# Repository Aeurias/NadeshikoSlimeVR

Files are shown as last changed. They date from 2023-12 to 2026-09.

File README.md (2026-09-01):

<h1 align="center">
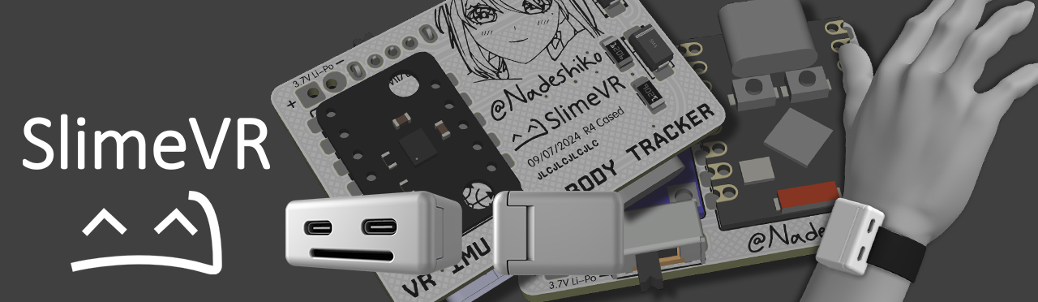
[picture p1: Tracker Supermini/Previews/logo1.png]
@Nadeshiko's Mini SlimeVR

@Nadeshiko's Supermini SlimeVR

</h1>

> [!IMPORTANT]
> For the old WEMOS D1 Mini variant please view the [D1 branch here](https://github.com/Aeurias/NadeshikoSlimeVR/tree/WEMOS-D1-Mini)

These are some of the smallest WiFi module based SlimeVR trackers possible, similar to [Gorbit99's Tiny Slime](https://github.com/gorbit99/tiny-slime), as small as extension trackers! The idea was for these to be a replacement for wired extension trackers, whose cables can get in the way and are prone to damage, and be a more useable and comfortable size for tracking locations such as shoulders, lower arms, neck, or head.

Due to how small these are, there is no option to connect an extension tracker, as that will only increase the overall size and cost of a whole tracker set.

@Nadeshiko's Supermini SlimeVRs run on a [ESP32-C3 Supermini](https://www.aliexpress.com/item/1005005877531694.html) with an IMU IC of your choice that has the same module profile as widely used SlimeVR IMU-module format like the [Mumo ICM-45686](https://shop.slimevr.dev/products/slimevr-mumo-breakout-module-v1-icm-45686-qmc6309)'s. They use the [TP4056 Unprotected lithium charger](https://www.aliexpress.com/item/1005005468881238.html) module for 3.7V LiPo batteries.

- 2.6cm x 3.8cm PCB design.
- Easy and very cheap to build.
- No wires needed to be soldered.
- Lightweight and smooth, clean case looks.
- 25mm strap width is supported.

## Index

- [PCB](#pcb)
- [Case](#cases)
- [Components](#components)
- [Basic Assembly Guide](#assembly)
- [Resources](#resources)
- [Detailed Assembly Guide](#detailed-assembly)
- [C3 WiFi Antennas](#esp32-c3-supermini-wifi-antennas)
- [Flashing Firmware](#flashing)
- [How to order PCB/3DPrints](#ordering)
- [Support](#support)

## PCB

The PCB lets every component be soldered on without any wire connections between the modules. This includes the diodes and resistors for battery sense and charge protection. The ESP32-C3 Supermini is on the back side to save on size and cost; a JST 2mm 2-pin connector can be added to make battery connections easier; an SK12D07VG 3-pin switch will be used to turn the tracker on or off.

PCBs can be ordered from [JLCPCB](https://cart.jlcpcb.com/quote/), [Elecrow](https://www.elecrow.com/pcb-manufacturing.html), [PCBGOGO](https://www.pcbgogo.com/pcb-fabrication-quote.html), [NextPCB](https://www.nextpcb.com/pcb-quote#/pcb-quote) or your preferred low cost PCB manufacturer.

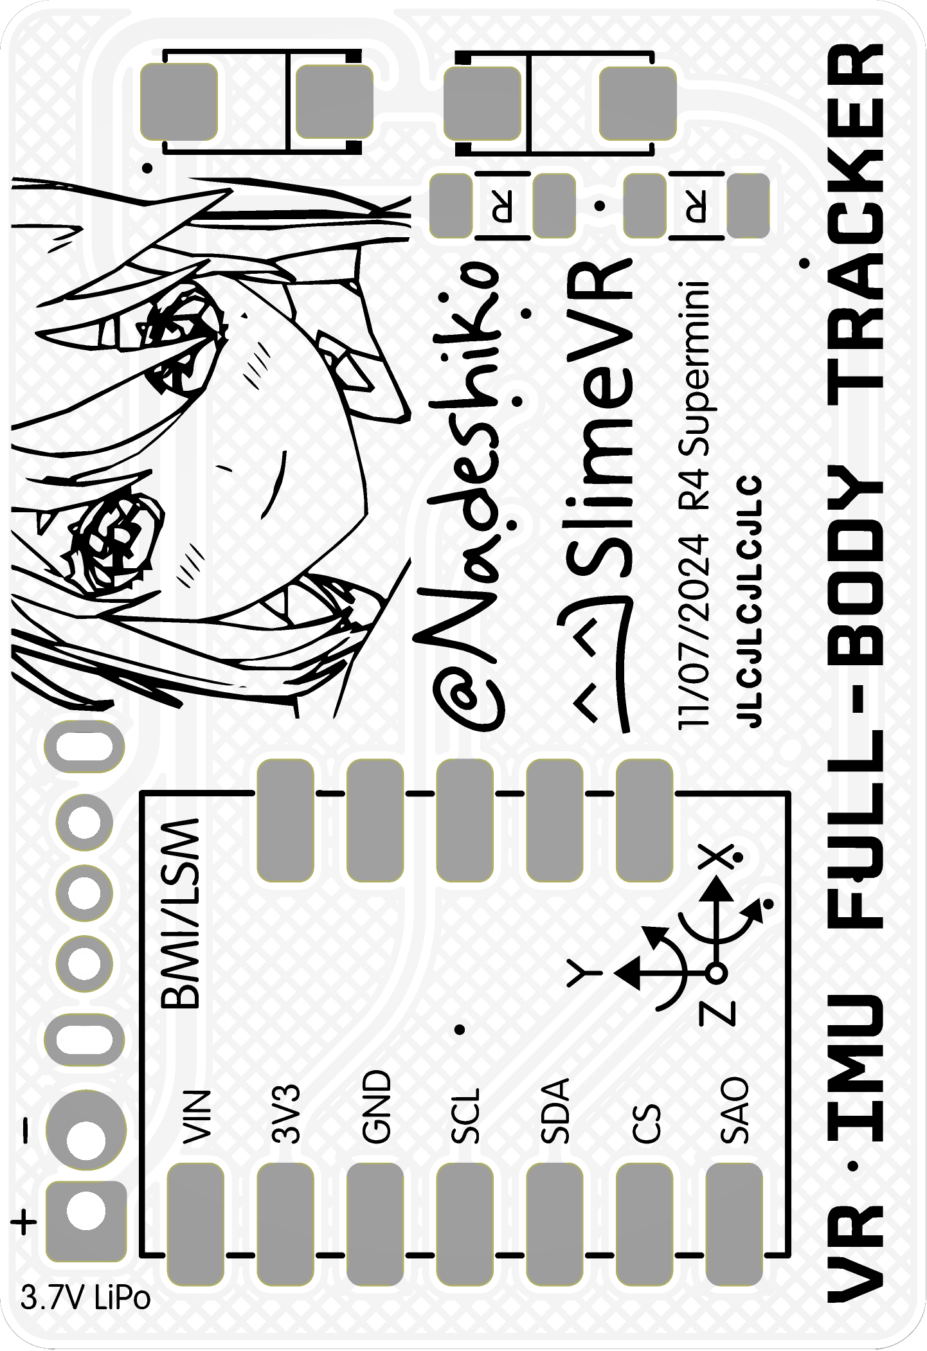
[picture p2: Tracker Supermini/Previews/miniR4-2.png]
Supermini Front
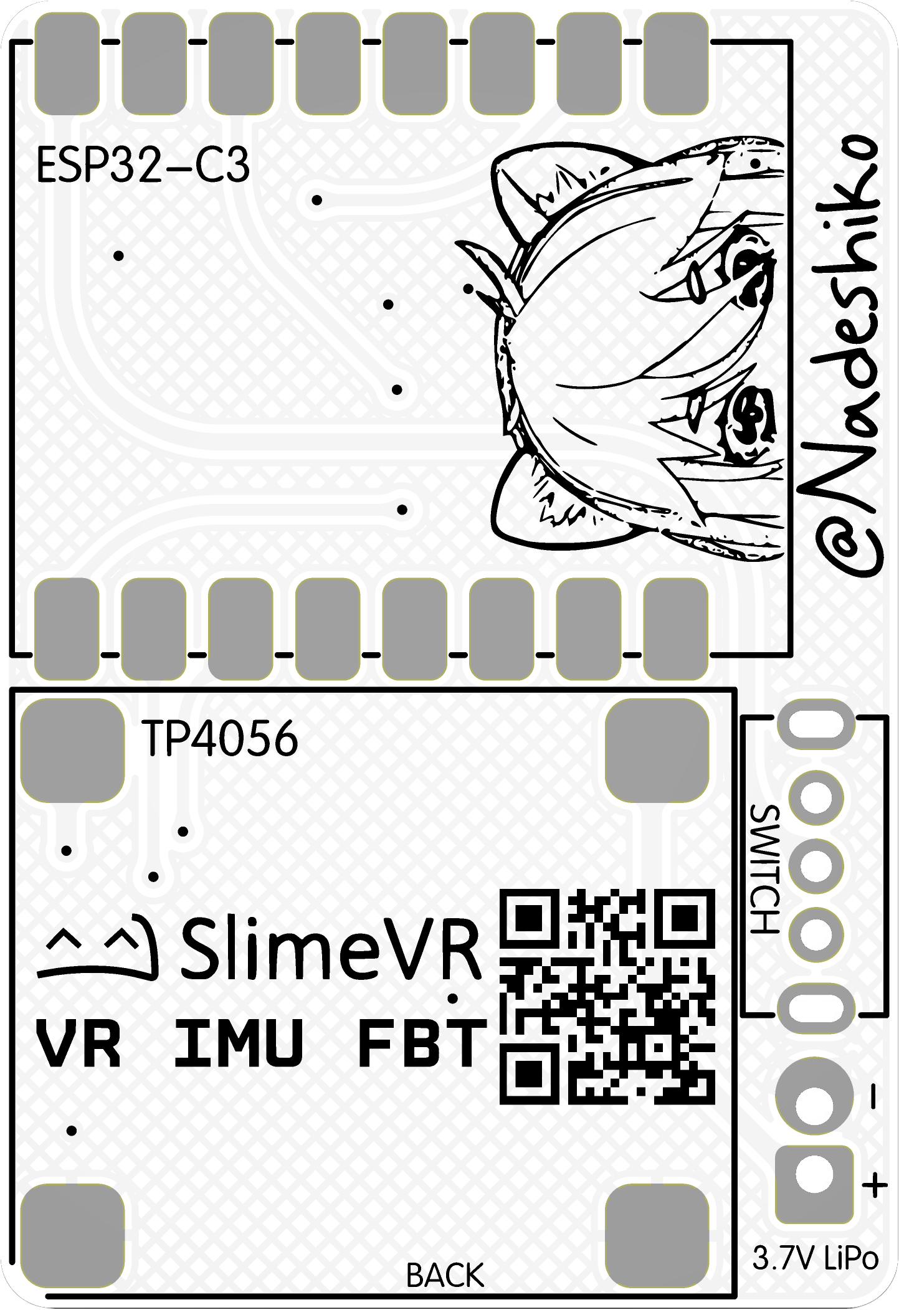
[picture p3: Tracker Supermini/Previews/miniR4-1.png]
Supermini Back
<div align="center">&nbsp;&nbsp;&nbsp;&nbsp;</div>

<p align="center">PCB Front/Back - 26mm x 38mm</p>

## Cases

The standard tracker case can house a 3.7V LiPo with Max LiPo cell dimensions 6x25x40mm, a 602535 or similar LiPo is recommended. There is also a double/taller battery variant of the case which allows stacking two batteries in parallel or a thick LiPo for longer runtime, this case is 5.6mm taller allowing LiPo cells to be 12mm tall.

The cases has been designed according to [JLCPCB/JLC3DP resin 3D printing guidelines](https://jlc3dp.com/help/article/212-3D-Printing-Design-Guideline). The case can be ordered from [JLC3DP](https://jlc3dp.com/3d-printing-quote) or [Elecrow](https://www.elecrow.com/3d-printing-service.html), and the resin to select on your order is up to you. I prefer the [**9000R**](https://jlc3dp.com/help/article/195-9000R---Photosensitive-Resin), [**CBY**](https://jlc3dp.com/help/article/437-CBY-Photosensitive-Resin), [**Black Resin**](https://jlc3dp.com/help/article/198-Black-Resin--Photosensitive-Resin), or equivalent low cost options..

It prints as two parts: a snap-fit closure with holes for strap, the TP4056 charger and ESP32-C3 USB ports, and the power switch.

25mm strap can be fitted to the cases; the best one to use is the non-slip elastic kind with plastic buckles and tri-buckles in the same size to make it easier to remove, more comfortable and adjustable. Hook and Loop style of strap can also be used.

The files for the standard case are:

- [NadeshikoSupermini-TOP.stl](Tracker%20Supermini/3D%20Print%20STL/NadeshikoSupermini-TOP.stl)

- [NadeshikoSupermini-BASE.stl](Tracker%20Supermini/3D%20Print%20STL/NadeshikoSupermini-BASE.stl)

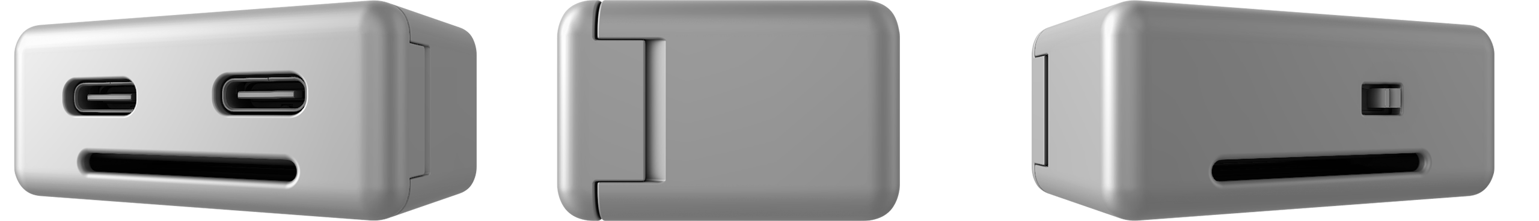
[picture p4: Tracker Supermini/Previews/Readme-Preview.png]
MiniPreview


<div align="center">30.2mm x 46.0mm × 19.52mm - 8.67cm³</div>

The files for the double stack battery case are:

- [NadeshikoSupermini-Double-Battery-TOP.stl](Tracker%20Supermini/3D%20Print%20STL/NadeshikoSupermini-Double-Battery-TOP.stl)

- [NadeshikoSupermini-Double-Battery-BASE.stl](Tracker%20Supermini/3D%20Print%20STL/NadeshikoSupermini-Double-Battery-BASE.stl)

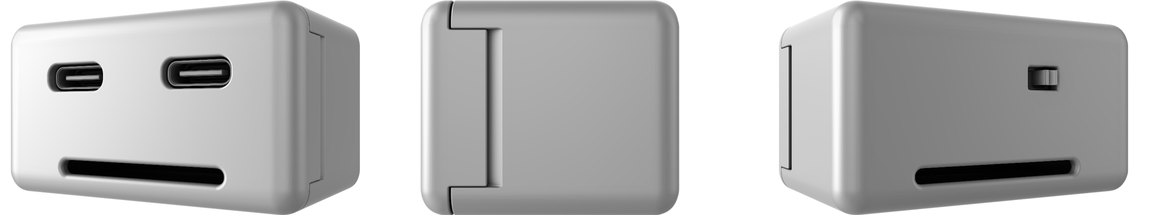
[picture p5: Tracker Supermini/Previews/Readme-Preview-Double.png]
MiniPlusPreview


<div align="center">30.2mm x 46mm × 25.12mm - 10.13cm³</div>

## Components

The component cost should come out to around £8/€9/$11 per tracker with the recommended ICM-45686 IMUs.
Quantity and prices listed below are per tracker expense and quantity used of each component.
Some of the smaller items are sold in pack sizes of 10/50/100 etc. which can build multiple trackers with.
Prices here are listed without any shipping costs, or pack sizes, or taxes, and may not be latest.

| Components per SlimeVR Tracker |  QTY  | £ | Link |
| --- | ----: | ----: | --- |
| @Nadeshiko Mini PCB | 1 |  0.39 | [JLCPCB](https://jlcpcb.com/) |
| @Nadeshiko Mini Case | 1 |  0.55 | [JLC3DP](https://jlc3dp.com/) |
| ESP32-C3 SuperMini V1/V2 | 1 |  1.59 | [AliExpress](https://www.aliexpress.com/item/1005006391993583.html) |
| SlimeVR Mumo ICM-45686 IMU Module | 1 |  5.00 | [SlimeVR](https://shop.slimevr.dev/products/slimevr-mumo-breakout-module-v1-icm-45686-qmc6309) |
| TP4056 Unprotected Charger Type-C | 1 |  0.11 | [AliExpress](https://www.aliexpress.com/item/32646649119.html) |
| SK12D07VG Slide Switch in 3/4/5mm | 1 |  0.04 | [AliExpress](https://www.aliexpress.com/item/1005005786809487.html) |
| 1206/3216 Resistors in 100K Ohm | 2 |  0.01 | [AliExpress](https://www.aliexpress.com/item/32982307507.html) |
| SS34 DO214AC Diodes | 2 |  0.01 | [AliExpress](https://www.aliexpress.com/item/1005005707508759.html) |
| LiPo Battery 6x25x40mm or smaller | 1 |  0.72 | [EHAO](https://www.aliexpress.com/w/wholesale-EHAO.html) or [XINJ](https://www.aliexpress.com/store/4885018/pages/all-items.html) or [ROGRAPO](https://www.aliexpress.com/store/910326412/pages/all-items.html) @AliExpress |

| Mounting Straps for Trackers | Link |
| --- | --- |
| 25mm Hook & Loop | [AliExpress](https://www.aliexpress.com/item/1005006326126306.html) |
| 25mm Elastic Strap & Buckles | [AliExpress](https://www.aliexpress.com/item/1005006096453678.html) |
| 25mm Tri Glide Adjustable Buckles | [AliExpress](https://www.aliexpress.com/item/1005006144047161.html) |
| 25mm Release Buckles | [AliExpress](https://www.aliexpress.com/item/1005006082194146.html) |

## Assembly

Using a solder helping hand will make putting everything on the PCB much easier! While soldering, keep your solder iron's tip tinned with solder when not in use to protect from oxidation. Use plenty of flux for surface mounts. Clean the PCBs from excess flux after soldering and testing, you can use PCB cleaner, isopropyl alcohol, acetone or nail varnish remover.

The basic steps of assembly for the main trackers are:

- [ ] 2x 1206 100K resistor and 2x SS34 diodes soldered in the correct orientation on the PCB.
- [ ] Solder an unprotected TP4056 charger flush to the PCB.
- [ ] Solder on a SK12D07VG slide switch.
- [ ] Solder the IMU module to the PCB.
- [ ] Solder the ESP32-C3 Supermini module flush to the PCB.
- [ ] Solder on the LiPo battery with the power switch in the OFF position in correct polarity.

Flashing:

- [ ] Power switch still in the OFF position; Flash firmware using the SlimeVR server or VSCode.
- [ ] When flashing, you want to choose `BOARD_LOLIN_C3_MINI` as the board.
- [ ] In Advanced options, change SDA Pin to `"6"`, SCL Pin to `"7"`, INT Pin to`"5"` and LED Pin to `"8"`.
- [ ] In Battery Sense section, select `BAT_EXTERNAL`, Shield Resistance to `0`, Battery Shield R1 & R2 to `100` kOhm, Battery Sense Pin to `1`.
- [ ] OPTIONAL: Use polyimide tape or equivalent on sharp corners and the LiPo battery to protect it from puncture.
- [ ] OPTIONAL: Remove the C3 chip antenna and add 29 to 31mm tinned wire for better WiFi signal (20-30dB better signal strength).

> [!TIP]
> When soldering make sure to use correct iron temperatures, a high quality flux cored solder wire and liquid flux in syringe. A multimeter will come extremely handy to test each component and solder joints. Check some guides on YouTube first if you've never soldered before!

## Detailed-Assembly

#### Step 1 - Resistors and Diodes

The diodes have an orientation marked by lines, which will match the line on the PCB diode footprint.
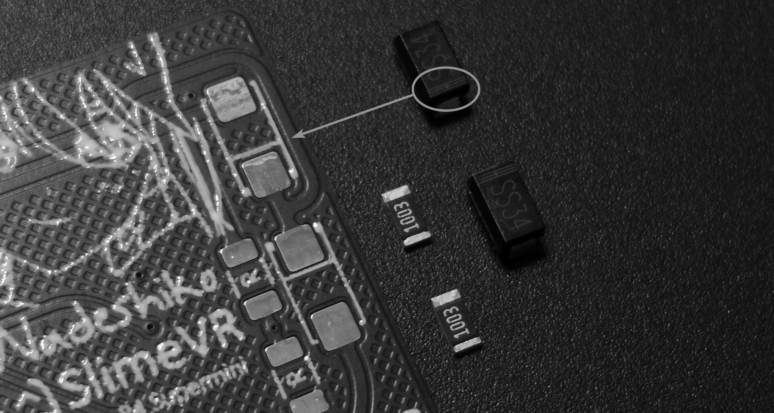
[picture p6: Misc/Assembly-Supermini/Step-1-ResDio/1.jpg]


Solder on the 100K resistors first, any orientation. Flux to make them easier to solder as it helps hold them and easier to clean later.
Add a smidge of solder on one of each of the diodes pads, so it can be the first pad to solder the diodes down to.
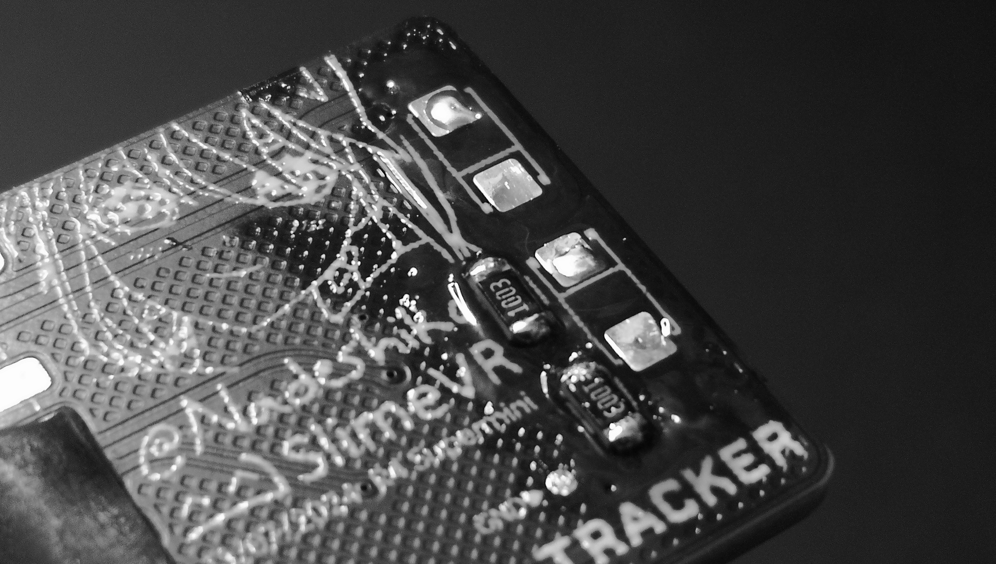
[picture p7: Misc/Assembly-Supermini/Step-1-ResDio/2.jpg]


Should look like this, with the diodes lines facing each other:
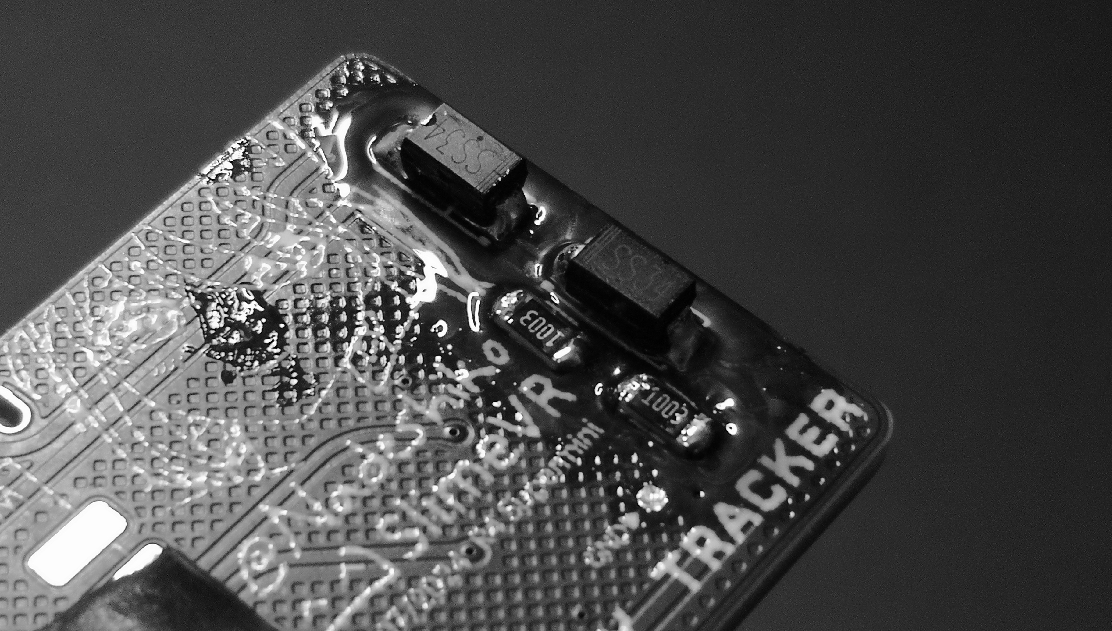
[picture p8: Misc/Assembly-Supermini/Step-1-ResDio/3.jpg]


#### Step 2 -  IMU Module

I'm using the Mumo ICM45686 IMU module here from the SlimeVR store, clamp it down on the backside of the PCB where you did the resistor/diodes with your solder helper clamps. I've added tiny bit of flux on the pads before doing this too:
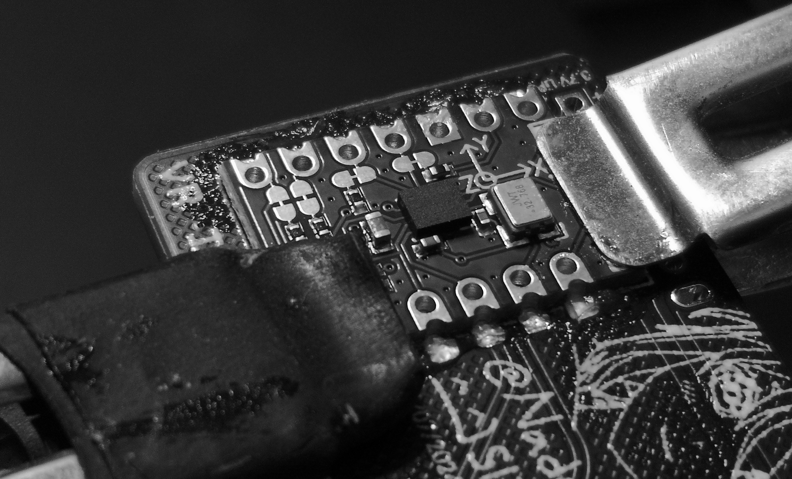
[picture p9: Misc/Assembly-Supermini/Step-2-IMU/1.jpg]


Solder the edge castellated holes of the IMU. If your module of choice does not have those and has drill holes, just use a bit more flux and do the holes instead.
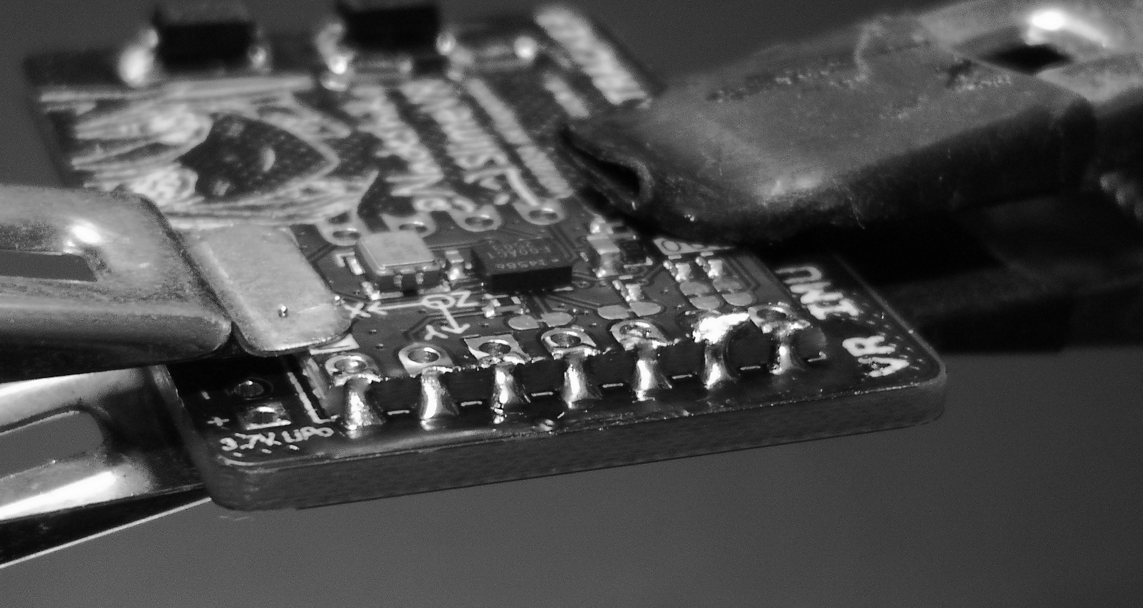
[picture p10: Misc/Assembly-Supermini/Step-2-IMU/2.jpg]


Do both left and right side, and double check visually to make sure there aren't any missed.
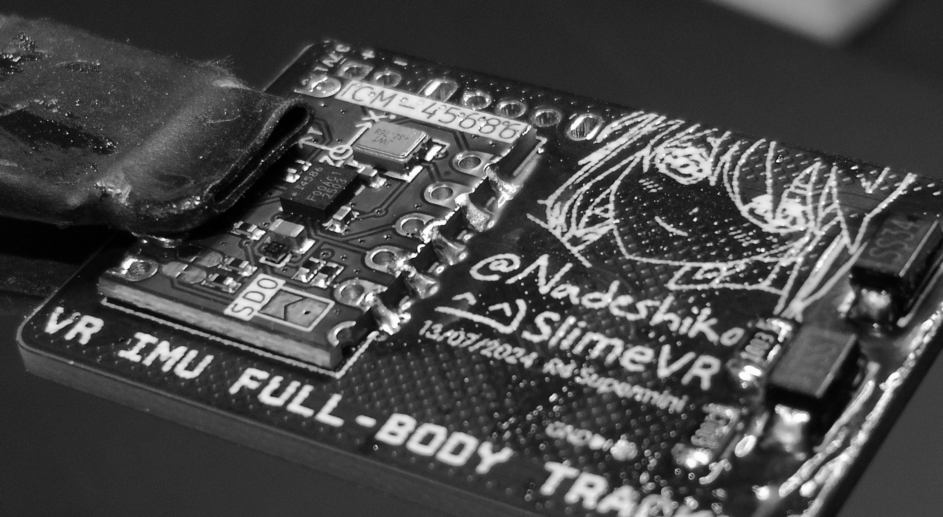
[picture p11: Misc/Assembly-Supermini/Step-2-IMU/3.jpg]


#### Step 3 -  Power Switch

The switch goes on the other side like shown in the image. It has its footprint there.
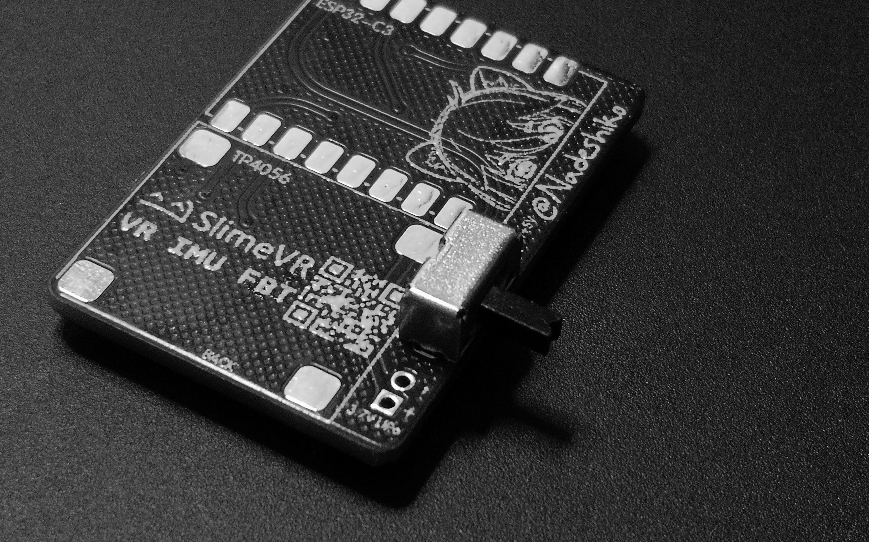
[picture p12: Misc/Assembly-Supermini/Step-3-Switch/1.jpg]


Clamp it flat to the PCB, but still have access to at least one of the legs on the backside of the PCB to solder initially.
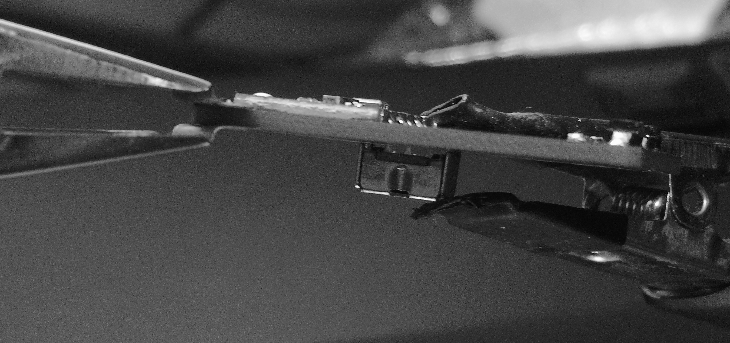
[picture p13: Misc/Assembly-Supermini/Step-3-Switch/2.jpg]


Flux those legs/pins and solder.
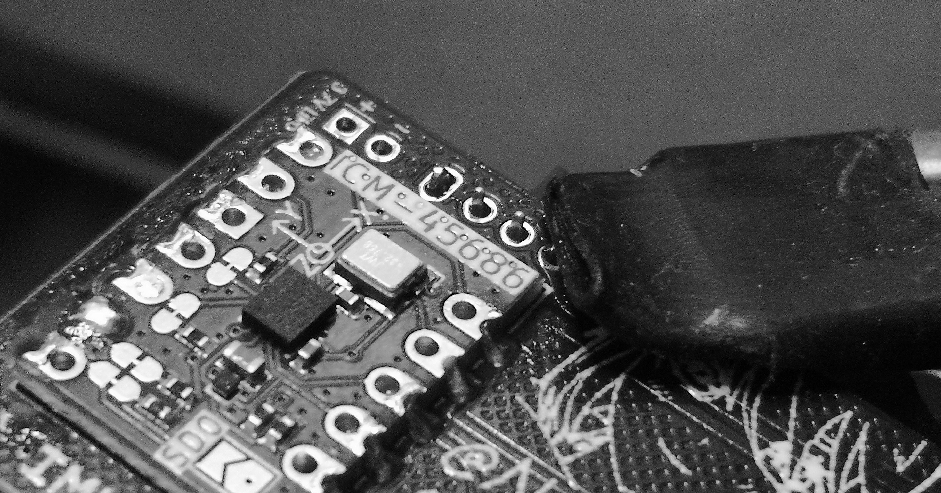
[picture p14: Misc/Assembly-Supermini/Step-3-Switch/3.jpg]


Flux will help pull solder through to the other side, which will make the switch very sturdy:
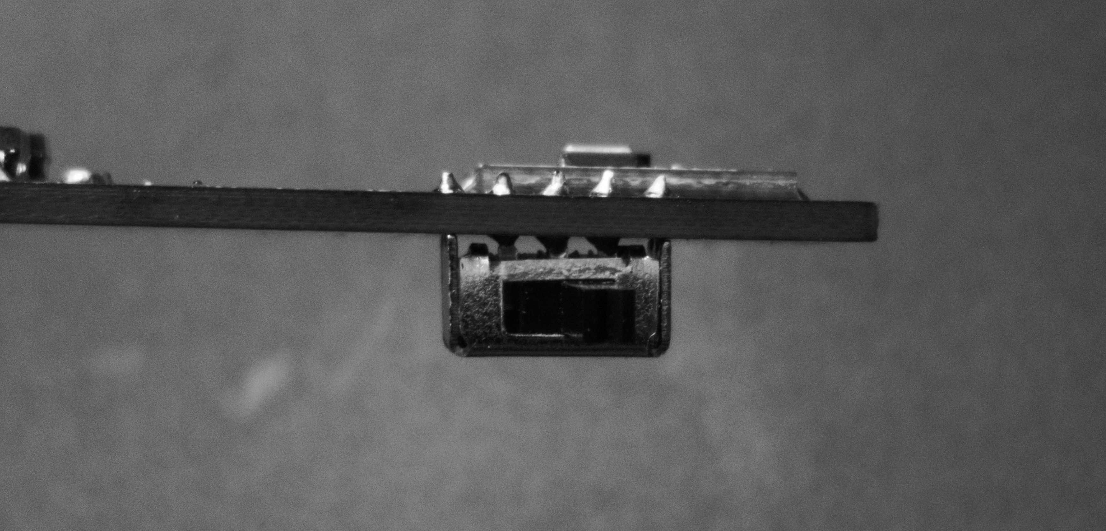
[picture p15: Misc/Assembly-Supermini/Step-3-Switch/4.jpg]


That does the backside of the PCB, you can clean the excess flux so its not sticky n ewwee for the rest of steps.
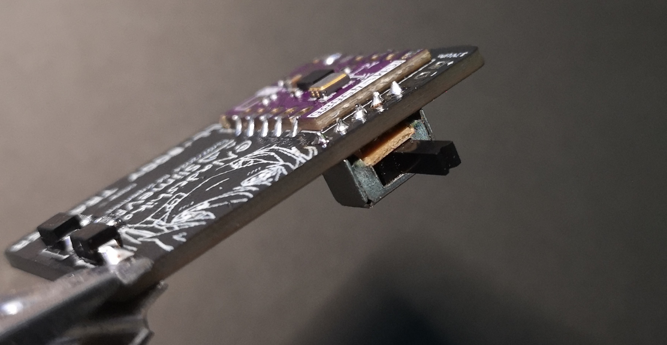
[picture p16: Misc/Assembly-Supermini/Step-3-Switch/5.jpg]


#### Step 4 - ESP32-C3 Supermini Module

There are few a Supermini C3 variants out there. The most common of these is the one on the right with the C3 antenna only which works perfectly for these slimes. For this guide, I'm using an C3 Supermini Plus which has the same footprint profile as the normal C3 Supermini, but has an flexible IPEX antenna included with it for improved range. I will also explain later on how to use the IPEX antenna properly on the Plus as it requires a small modification for it to work, or how to modify the non IPEX ones for better signal strength.


Soldering the C3 is same as the IMU earlier. Just slightly larger and few more pads. Start with fluxing the pads slightly.
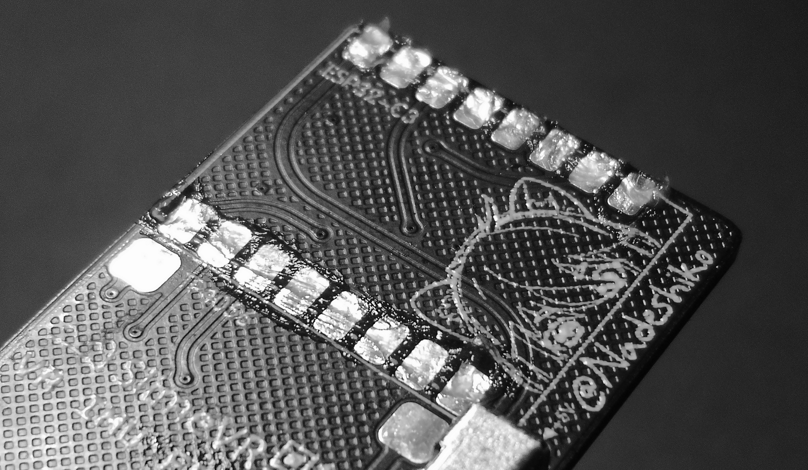
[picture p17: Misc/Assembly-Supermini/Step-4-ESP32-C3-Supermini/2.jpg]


Clamp down the C3 with your solder helping hands in the correct position, lined up with the footprint on the PCB.
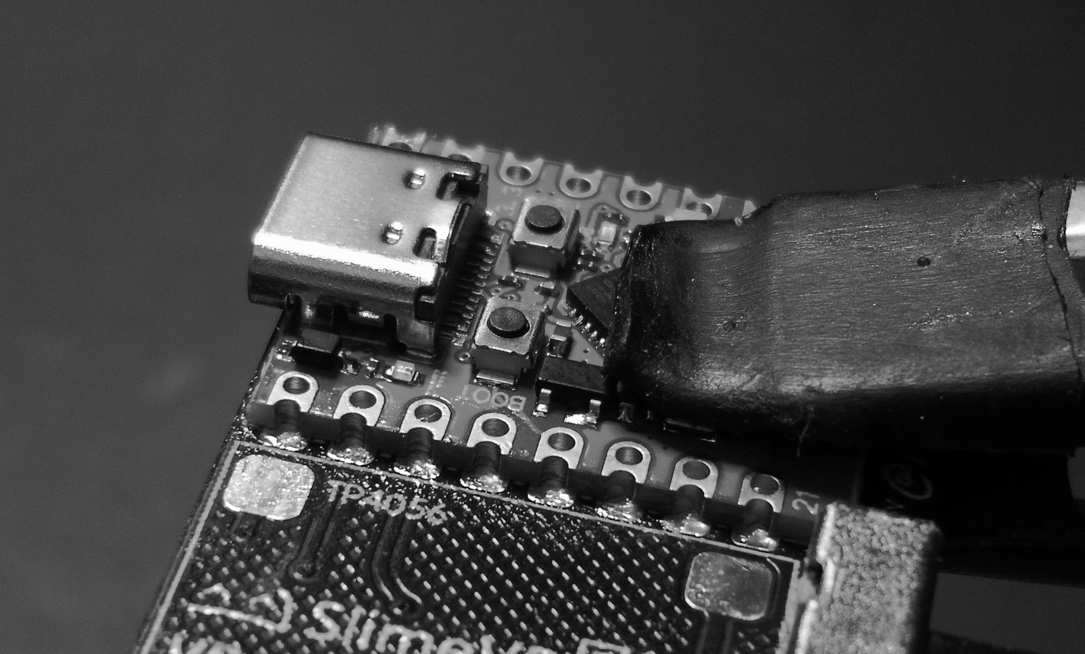
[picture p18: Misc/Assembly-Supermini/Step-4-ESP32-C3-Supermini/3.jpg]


Solder the edge castellated holes of the C3, both left and right side, and double check visually to make sure there aren't any missed pads.
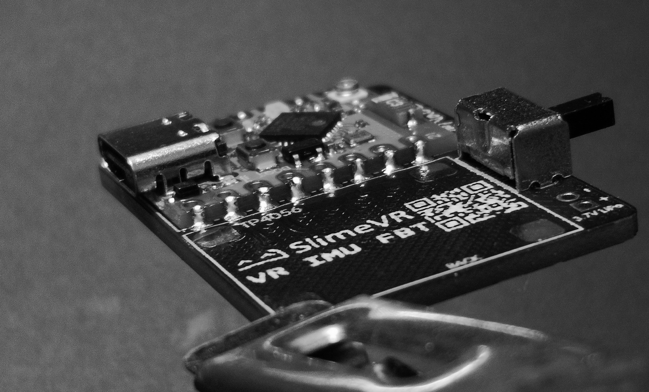
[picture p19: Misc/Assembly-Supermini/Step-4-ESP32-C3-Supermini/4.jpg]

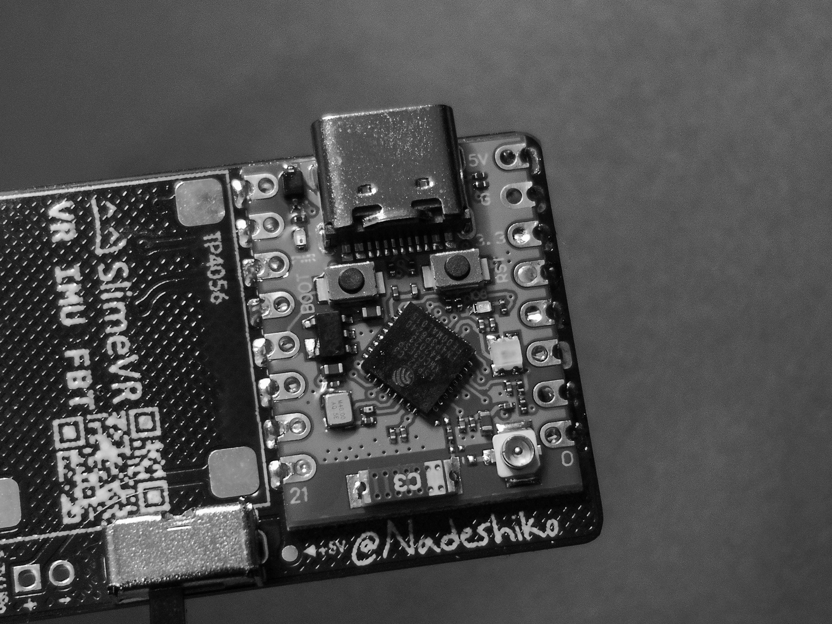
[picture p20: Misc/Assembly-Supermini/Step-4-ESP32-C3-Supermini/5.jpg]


#### Step 5 - TP4056 Unprotected Charger Module

The TP4056 3.7v Lithium battery charging module comes in many sizes and USB styles. You want the unprotected variant with 4 holes:
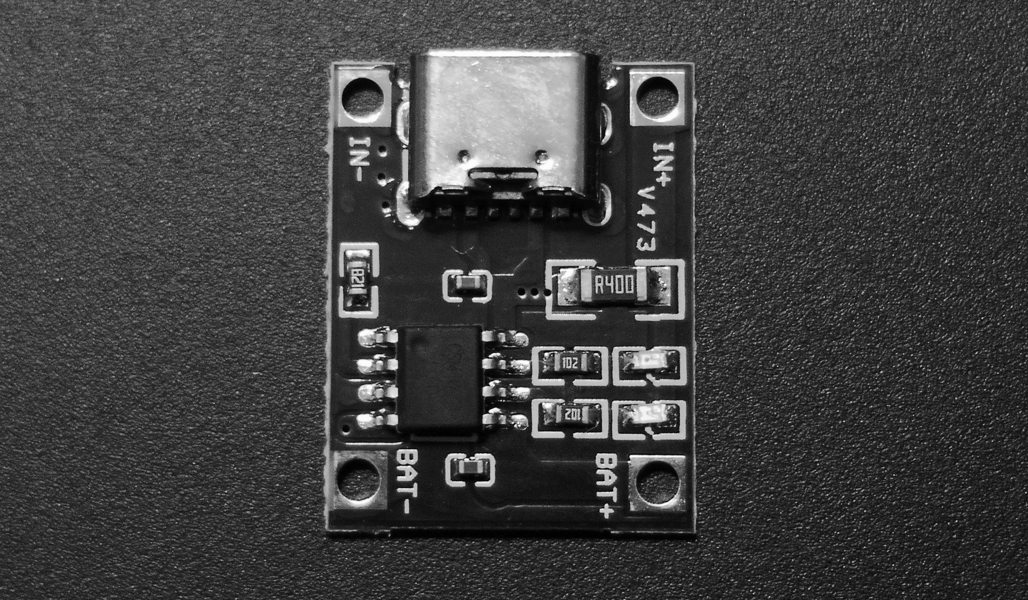
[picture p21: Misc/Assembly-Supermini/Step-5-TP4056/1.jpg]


Flux the PCB pads and even some of the holes on the TP4056 just to make it easier to solder and then clamp it down.
It may not align with the footprint perfectly like mine, as these come with small variance in dimension between vendors.
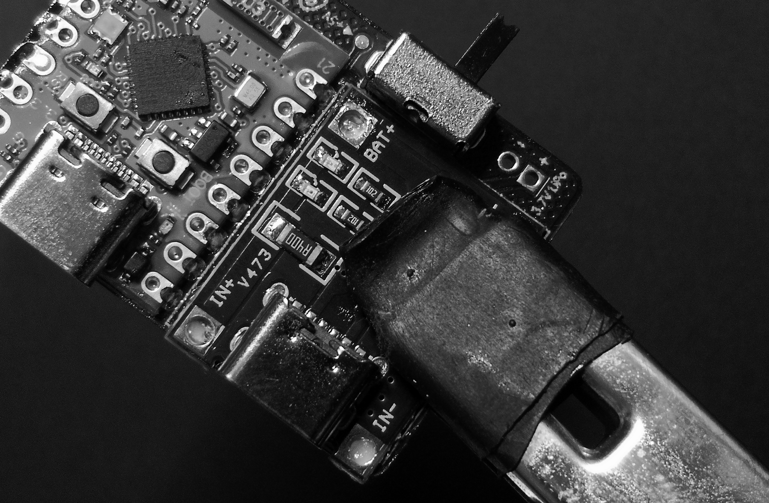
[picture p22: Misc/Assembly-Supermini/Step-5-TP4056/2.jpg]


There may be a small overhang on the TP4056, mostly okay, but this can be filed/sanded down if it causes issues with fitment into the case.
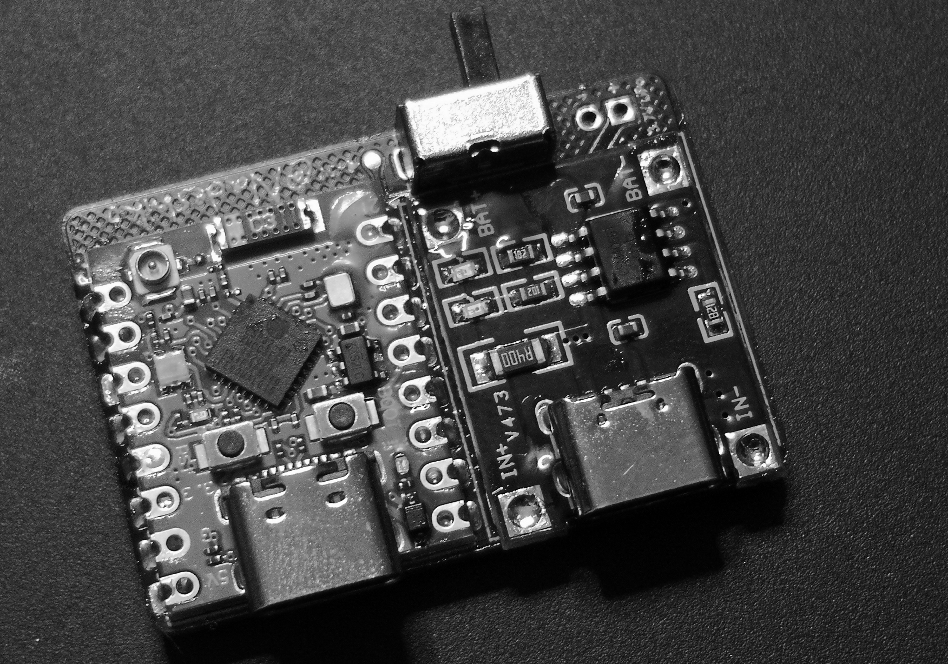
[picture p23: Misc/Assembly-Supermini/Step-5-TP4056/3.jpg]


#### Step 6 -  3.7v LiPo Battery

The tracker is basically complete and useable, and can be flashed right away. But we'll continue this guide with the battery. I am using a 602030 battery here that I was able to find super cheap on AliExpress, which is 6mm x 20mm x 30mm as the name states. This Supermini PCB/Case SlimeVR can house up to a 6x25x40mm battery. Thicker batteries like 7mm could fit, but we need a gap between the battery and the inside wall of the case for the strap to pass through.

We need to cut the wire down as it's arrives bit too long. Cut them short around where the arrow is indicated. For smaller batteries you might need a bit more wire, and less for larger batteries, so its fits in the case easier.
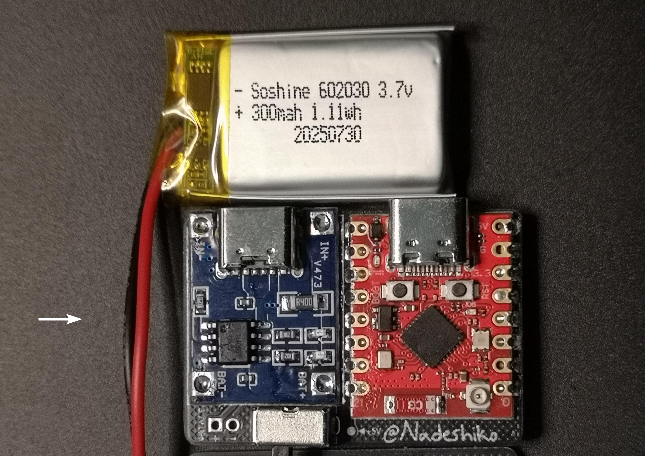
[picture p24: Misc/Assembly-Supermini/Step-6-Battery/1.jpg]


Strip the ends of the cable so we can solder it on the PCB.
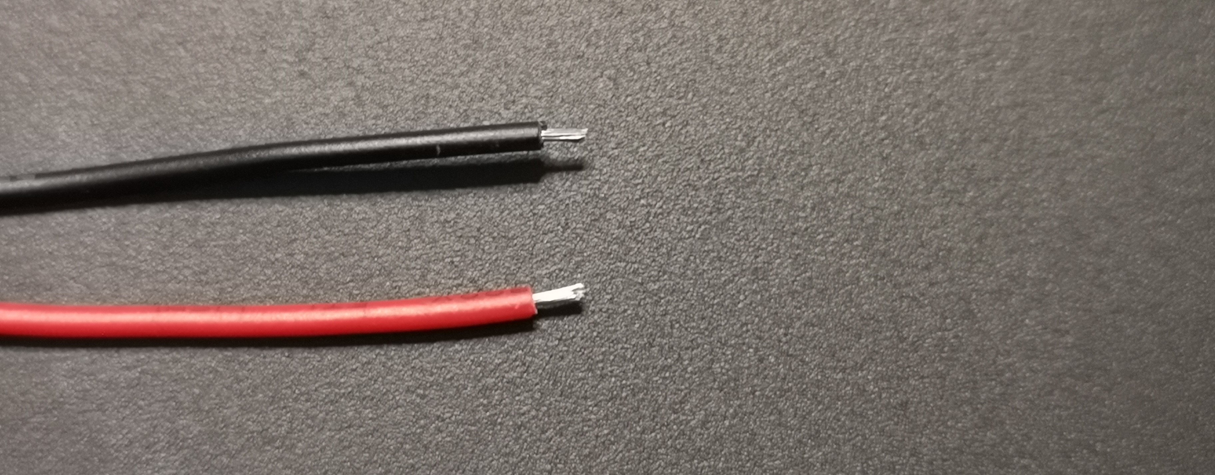
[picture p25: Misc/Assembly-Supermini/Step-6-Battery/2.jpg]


Flux the cable ends and the +/- holes on the PCB and solder it up. Making sure it's correct polarity.
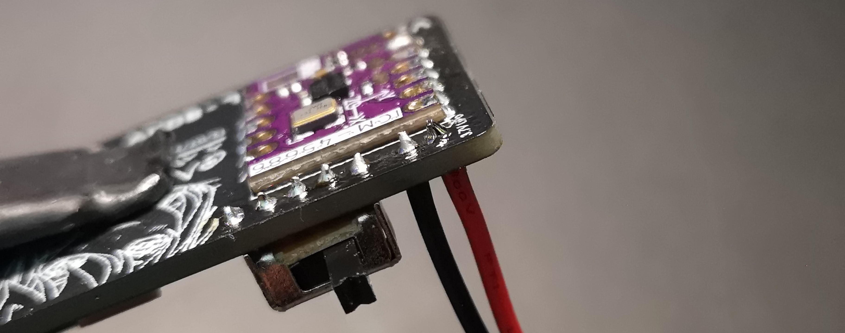
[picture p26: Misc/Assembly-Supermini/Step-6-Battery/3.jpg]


The wires can be shaped/bent around, so the battery sits nicely on top of the modules/USB's.
If wires too long you can redo it and cut it shorter. If too short, you can undo the yellow polyimide tape on the battery and redo the wires on it.
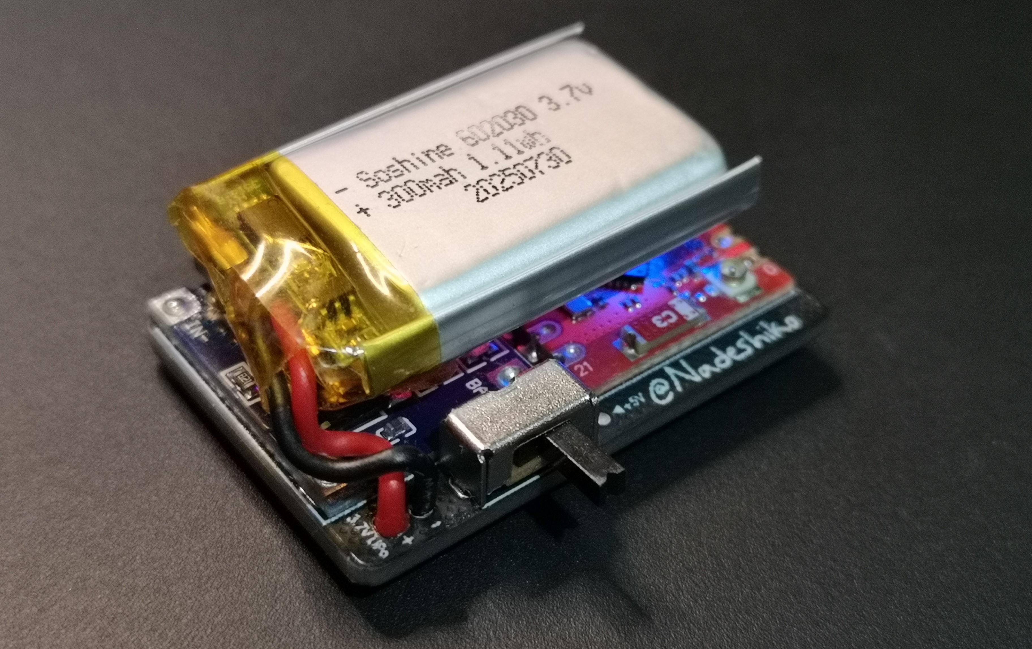
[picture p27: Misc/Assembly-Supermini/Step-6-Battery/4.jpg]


## ESP32-C3 Supermini WiFi Antennas

There are two antenna modifications you can do to improve WiFi range and signal reliability on the ESP32-C3 Supermini V1 & V2. Both involve removing the stock C3 chip antenna.

### Option A - IPEX Antenna (Plus/V2 variant only)

For the Plus/V2 variant C3 Supermini, you must solder a bridge between the two points marked with the green arrow to use the IPEX antenna.
This alone is enough to get the antenna to work, however the C3 chip antenna must be removed as it causes imperfect impedance matching and signal loss.
As some power leaks into the unused antenna, this reduces the efficiency and dB of the external antenna. For that, simply de-solder the red arrow marked C3 chip antenna, and then bridge green point with solder or a 0 Ohm resistor, and attach the IPEX antenna.
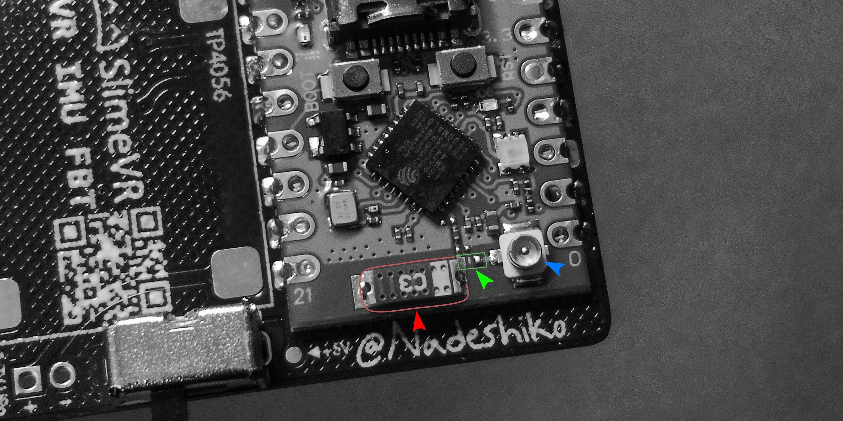
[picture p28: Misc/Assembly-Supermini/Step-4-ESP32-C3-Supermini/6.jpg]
IPEX


### Option B - Quarter-Wave Wire Antenna (any C3 Supermini variant) - Recommended

Instead of using an IPEX antenna, you can solder a simple wire directly onto the C3 chip antenna's main solder pad to create a Quarter-Wave ($\lambda/4$) antenna. This works on any C3 Supermini variant and gives around 25 to 30 dBm signal strength gain over the stock chip antenna.

**Why a wire antenna?** The stock chip antenna on the C3 is compact but weak. A quarter-wave wire antenna is tuned to 2.4 GHz WiFi and naturally approaches the 50-ohm impedance the ESP32-C3's radio is designed for, meaning more power goes into the air and less is reflected back into the ESP32 chip.

**Wire length:** Cut a piece of solid core wire to **31mm**. This length comes from the quarter-wave formula adjusted for the velocity factor of copper wire:

$$L = \frac{c}{f \times 4} \times K \approx 30.6 \text{ mm} \times 0.96 \approx 29.5 \text{ mm}$$

Where *c* is the speed of light (~300,000 km/s), *f* is 2.45 GHz (center of the band), and *K* is the velocity factor (~0.96 for copper wire).

> [!TIP]
> The extra ~1.5mm accounts for the solder joint which doesn't radiate efficiently, the C-shape bending which creates stray capacitance that makes the antenna electrically shorter than its physical length, and the fact that WiFi spans 2.412 to 2.484 GHz so the true ideal length varies by channel. Starting slightly long and trimming is standard practice in RF, since you can always cut shorter but can't add length back.

**Steps:**

1. De-solder and remove the C3 chip antenna from the board.
2. Cut a piece of wire to 31mm. Tin the wire with solder if it's stranded so its one solid conductor.
3. Solder the wire onto the chip antenna's main solder pad.
4. Bend the wire into a **C shape** so it loops back, forming a small circular loop. This shapes the radiation pattern into an omnidirectional "donut" and improves how the antenna couples with the board's ground plane.

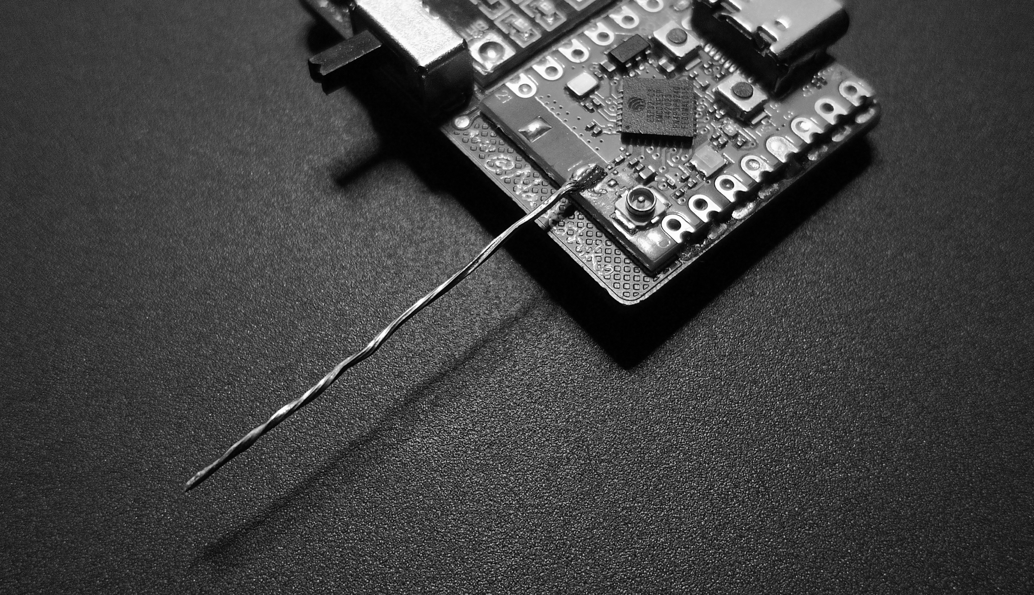
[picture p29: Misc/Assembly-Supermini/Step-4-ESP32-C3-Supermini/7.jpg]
Wire antenna soldered to C3 chip antenna pad

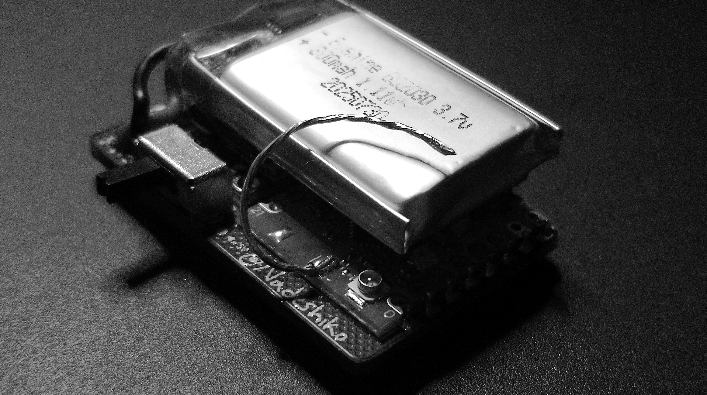
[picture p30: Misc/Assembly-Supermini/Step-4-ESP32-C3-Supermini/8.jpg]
Wire antenna bent into U shape for radiation pattern


You can place the wire loop on either side of the PCB, but the backside (away from the battery) is ideal. On that side, the signal only has to pass through the case to reach your router. If it's on the front side, the signal has to travel through the battery, PCB, and case. However you need to make sure it does not touch the PCB as the ground fill plane will affect the signal:

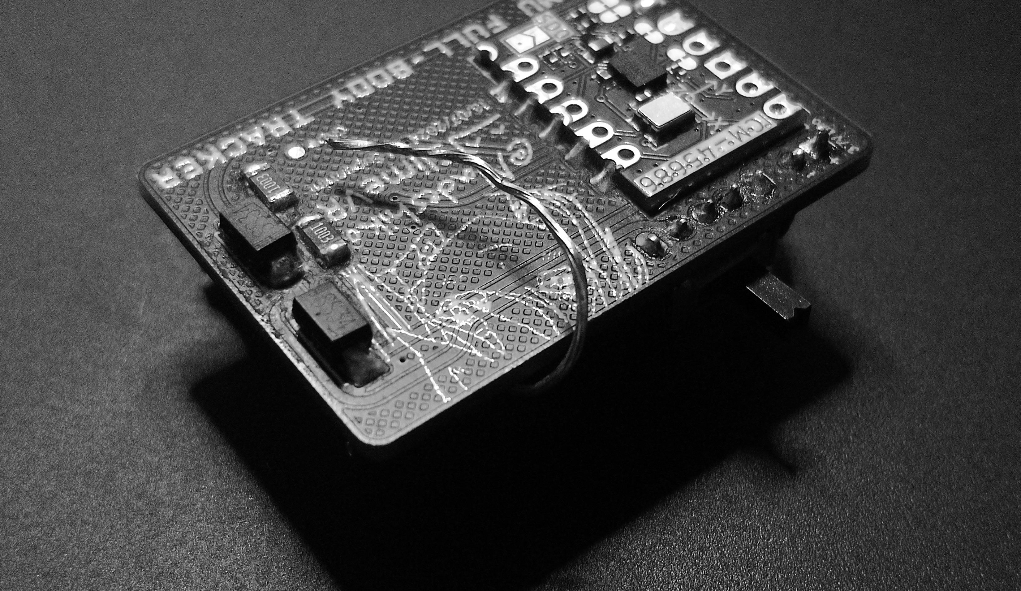
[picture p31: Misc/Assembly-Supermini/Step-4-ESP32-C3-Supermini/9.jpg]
Wire antenna bent under the PCB so it only travels through the case


> [!TIP]
> Solid core wire is ideal, but you can also use the offcut from the battery cable. Tin it thoroughly with solder so the strands fuse into a single rigid conductor. Tinning gives the wire a smoother outer surface which is better for RF at 2.4 GHz (due to the skin effect), and makes it stiff enough to hold the C shape without shifting and detuning the antenna.

**Why a C shape?** If you leave the wire straight instead of doing a loop/U/C, the signal becomes more directional like a water hose pointing in one direction rather than spraying evenly around you and the tracker may lose connection depending on which way your body is facing relative to your router.

> [!NOTE]
> Despite being a manufactured antenna, the IPEX ESP32-C3 Supermini Plus/V2 actually underperforms compared to the wire antenna (Option B). The U.FL connector and coaxial cable introduce signal loss at 2.4 GHz, and the IPEX antenna expects a ground plane. The wire antenna avoids all of this. It's a full quarter-wave element with a direct solder connection and zero cable loss.

## Flashing

Flashing these Slimes is the same as flashing [Gorbit99's Tiny Slime](https://github.com/gorbit99/tiny-slime?tab=readme-ov-file#flashing). I will show you how to flash it directly from the SlimeVR server and the online firmware flash tool, and how to solve any flashing or WiFi setup issues you may run into.

> [!NOTE]
> For the online firmware flash tool, you can [follow this link](https://slimevr-firmware.bscotch.ca/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) with everything already inputted for the flashing. You just need to change the firmware version and select your primary IMU type.

#### Flashing with the online firmware tool

- [Online Firmware Flasher](https://slimevr-firmware.bscotch.ca/)
- [Online Firmware Flasher Alternative](https://slimevr.shinebright.dev/)

1. You want to be on the latest firmware in the drop down selection.
2. For the board type, you want to choose `BOARD_LOLIN_C3_MINI`.
3. Open **Advanced Options**, change **SDA Pin** to `6`, **SCL Pin** to `7`, **INT Pin** to `5`, and **LED Pin** to `8`.
4. For **Primary IMU**, select the one you have.
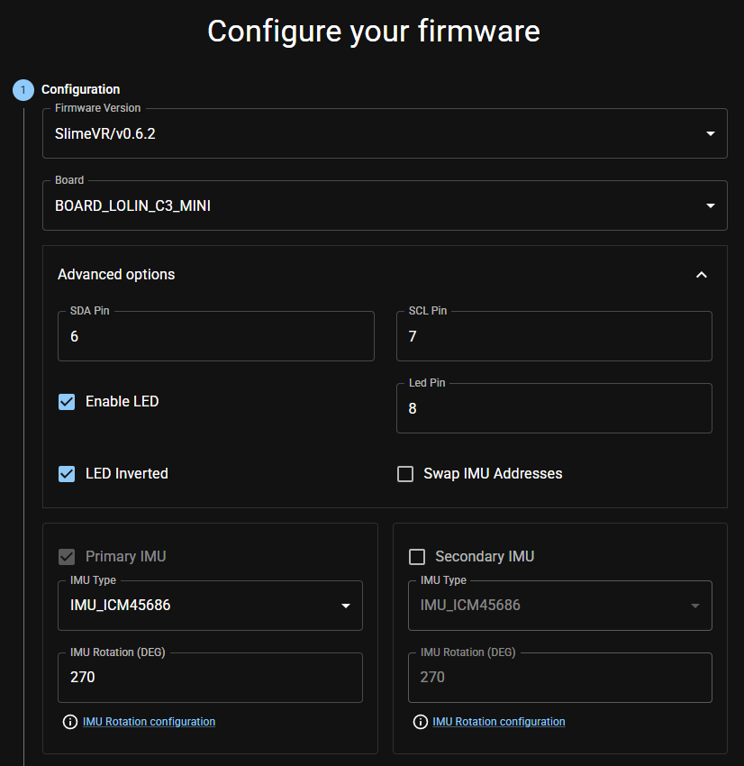
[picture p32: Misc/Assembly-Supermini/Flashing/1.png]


Next we do the Battery Sense settings.

1. Click open **Battery Sense (optional)** section, select **Battery Type** as `BAT_EXTERNAL`.
2. Change **Battery Shield Resistance (kOhm)** put `0` .
3. Set **Battery Shield (kOhm)** to `100` for both Battery Shield **R1** and **R2**.
4. For **Battery Sense Pin** set to pin `1`.
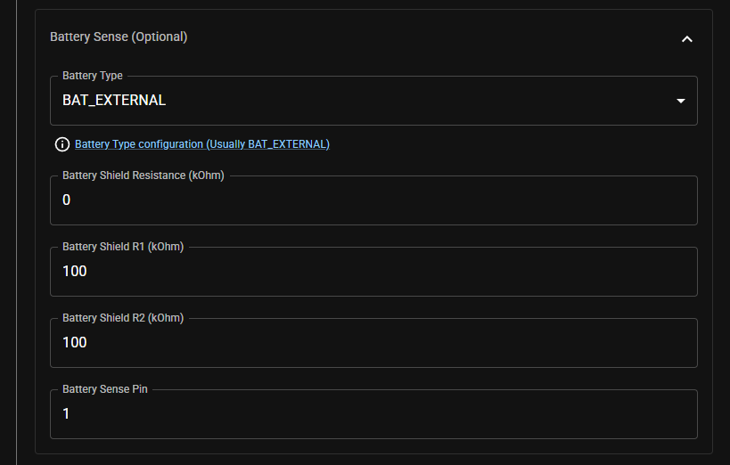
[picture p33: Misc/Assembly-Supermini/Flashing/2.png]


Open the Wi-Fi settings section and input your 2.4GHz Wi-Fi credentials.

Now on the Supermini. Set it to flashable mode, first double check that it's turned off at the switch, Hold down the left button on it labeled **"BOOT"**, and while holding it down, plug it into your PC.

After flashing you need to manually reset the Supermini. This can be done by either hitting the reset button labeled **"RST"** or by just unplugging it and powering it on.

If everything went well and your SlimeVR server is turned on, it should be able to connect and appear in there.

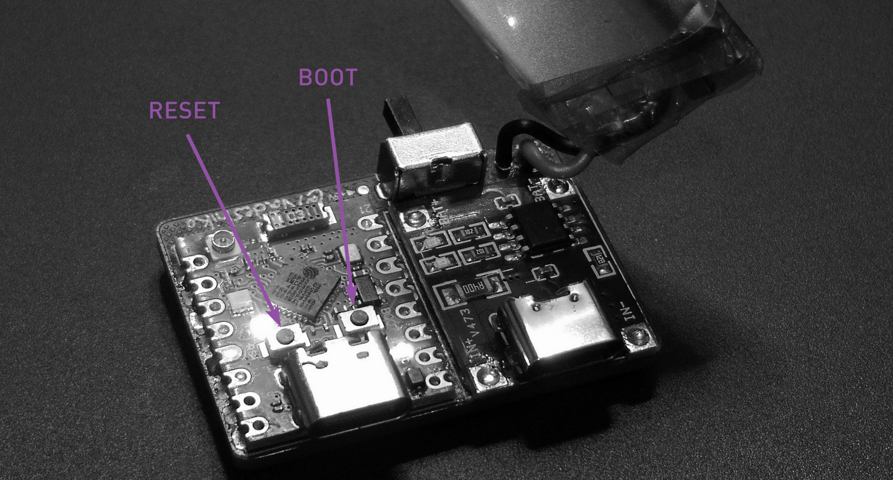
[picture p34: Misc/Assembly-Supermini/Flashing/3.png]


> [!NOTE]
> Another flash mode method is by holding the **"BOOT"** button, click the **"RST"** and then release **"BOOT"** button

If however it doesn't appear in the SlimeVR server and nothing is showing in the server's serial console, you can use this [Online Serial Terminal](https://terminal.spacehuhn.com/) with the SlimeVR server closed.

Use the serial console if it doesn't appear to connect to WiFi, forgot to set WiFi credentials when flashing, or tracker works over USB but not over WiFi.

Use the serial command `SET WIFI XXXX YYYY` where `XXXX` is your 2.4GHz name, and `YYYY` is the password, both are case sensitive.

For everything else, use the SlimeVR Documentation, as it contains information for proper SlimeVR server setup, calibration, and wearing.

Sometimes flashing the latest firmware might not work at all on the C3 Supermini's and certain IMU combos. Thus you can try older versions such as 0.6.2 with VSCode flashing method and then upgrade it to latest through the SlimeVR server afterwards.

## Resources

Useful Links:

- [SlimeVR Documentation](https://docs.slimevr.dev/)
- [SlimeVR Github](https://github.com/SlimeVR/)
- [SlimeVR Discord](https://discord.gg/SlimeVR)
- [Online Firmware Flasher](https://slimevr-firmware.bscotch.ca/)
- [Online Firmware Flasher Alt](https://slimevr.shinebright.dev/)
- [SlimeVR-Tracker-ESP](https://github.com/SlimeVR/SlimeVR-Tracker-ESP)
- [SlimeVR-Server](https://github.com/SlimeVR/SlimeVR-Server)

## Ordering

### PCB

Ordering the PCB and 3D Prints is easy. Head to the [releases](https://github.com/Aeurias/NadeshikoSlimeVR/releases) section and download the 3D print .stl files, and the PCB Gerber .zip files.

For PCB ordering, head over to  [JLCPCB](https://cart.jlcpcb.com/quote/) and upload the gerber .zip files. Use the settings below on the order page.

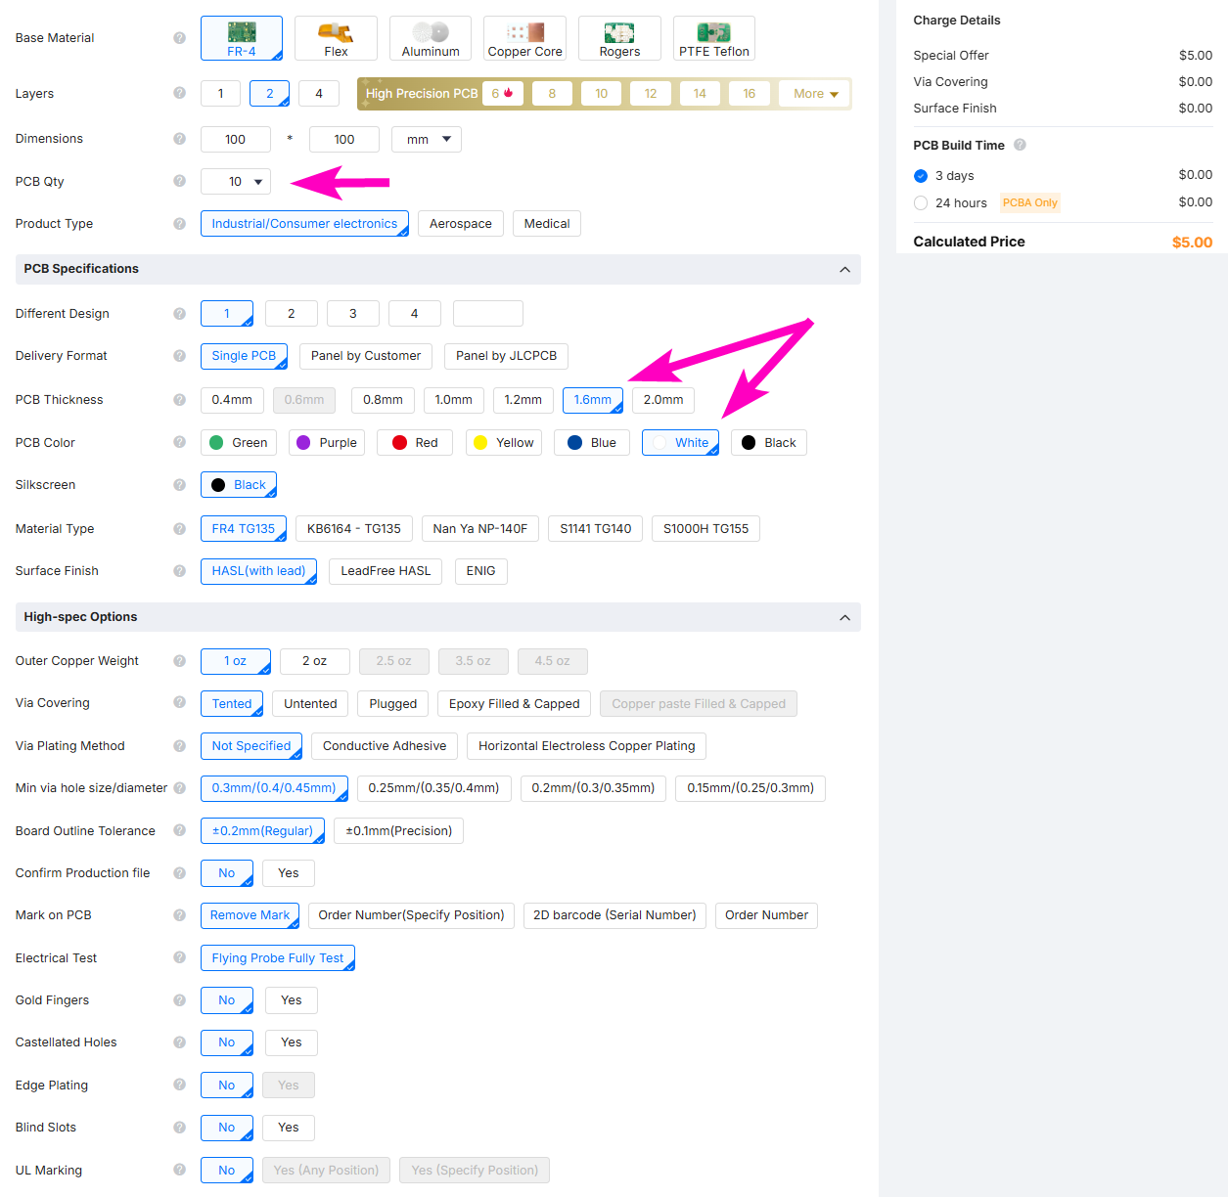
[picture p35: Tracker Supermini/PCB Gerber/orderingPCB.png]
Ordering


They can also be ordered from your preferred PCB manufacturer.

### Cases

For 3D Print case ordering, head over to [JLC3DP](https://jlc3dp.com/3d-printing-quote) and upload the .stl files for each model, including the top/body and base/end cap etc. One case comes in two parts, so make sure you upload both halves. Then use the settings below on the order page and set the quantity of each part to the number of trackers you are building. The available SLA material and prices will vary, as the model has been designed to be used with any of the SLA resins, any of the cheapest options will be good enough for the trackers, typically the opaques are the best. I recommend the 9000HE. You will get a warning of printing risk, such as walls being too thin in a certain spot, this can be ignored and is done by design intention.

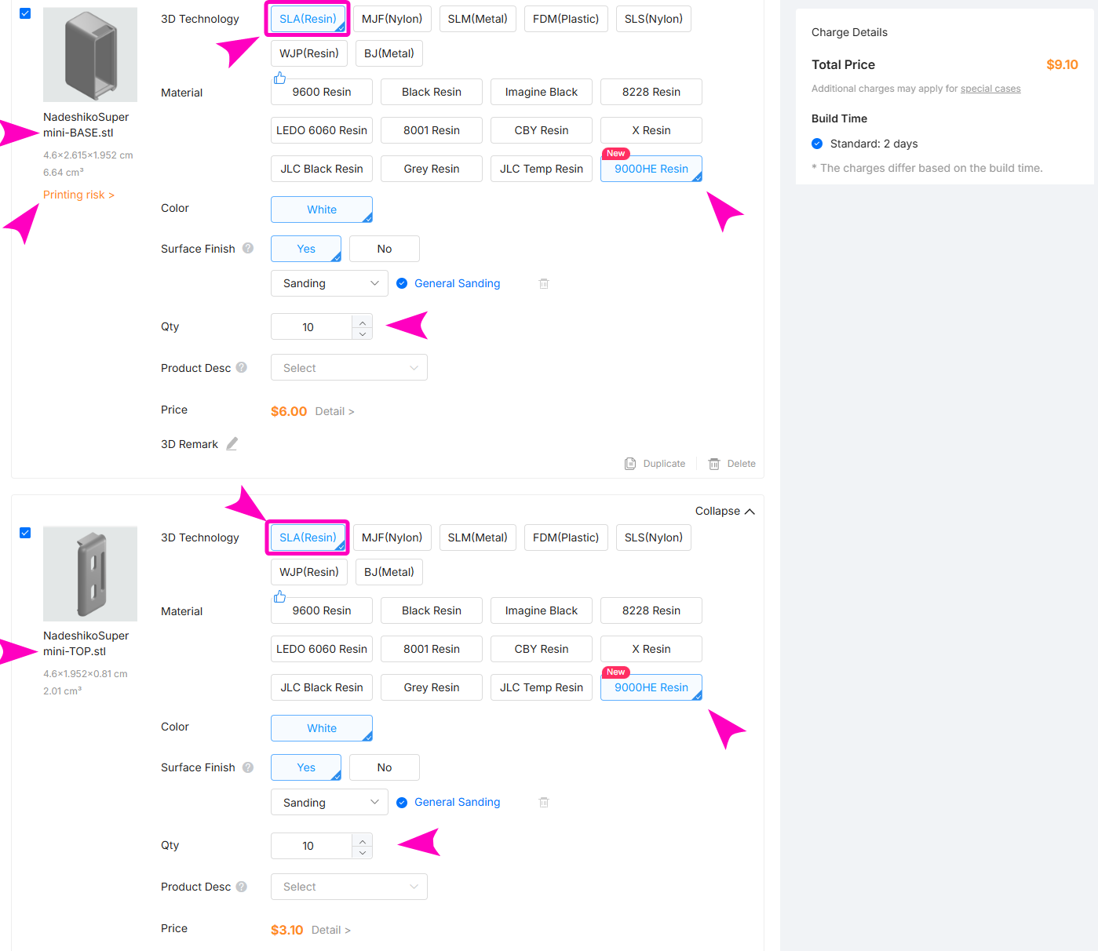
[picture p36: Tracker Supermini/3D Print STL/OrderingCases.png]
Ordering


Cases can also be ordered from your preferred 3D print services.

## Support

If you are unsure of an assembly or flashing step, you can always reach out to me on Discord.

[@aeurias](https://discord.com/users/240905316013703169), or add on VRChat: [Nadeshiko ~](https://vrchat.com/home/user/usr_f6e358a4-a938-46eb-bfb2-4fee10bd21e5).

## License  

<sub>
Copyright Nadeshiko 2023.<br> 
This source describes Open Hardware and is licensed under the <a href="LICENCE.txt">CERN-OHL-W v2</a>.<br> 
You may redistribute and modify this documentation and make products using it under the terms of the CERN-OHL-W v2 (https://cern.ch/cern-ohl) .<br> 
This documentation is distributed WITHOUT ANY EXPRESS OR IMPLIED WARRANTY, INCLUDING OF MERCHANTABILITY, SATISFACTORY QUALITY AND FITNESS FOR A PARTICULAR PURPOSE. Please see the CERN-OHL-W v2 for applicable conditions.<br> 
Source location: https://github.com/Aeurias/NadeshikoSlimeVR<br> 
As per CERN-OHL-W v2 section 4.1, should You produce hardware based on these sources, You must maintain the Source Location visible on the PCB of the @Nadeshiko SlimeVR tracker or other product you make using this documentation. 
</sub>

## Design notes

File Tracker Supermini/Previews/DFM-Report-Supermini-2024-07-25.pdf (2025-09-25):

## HQDFM Design for Manufacture(DFM) Report

| Milling Density | 132.8730m/m²

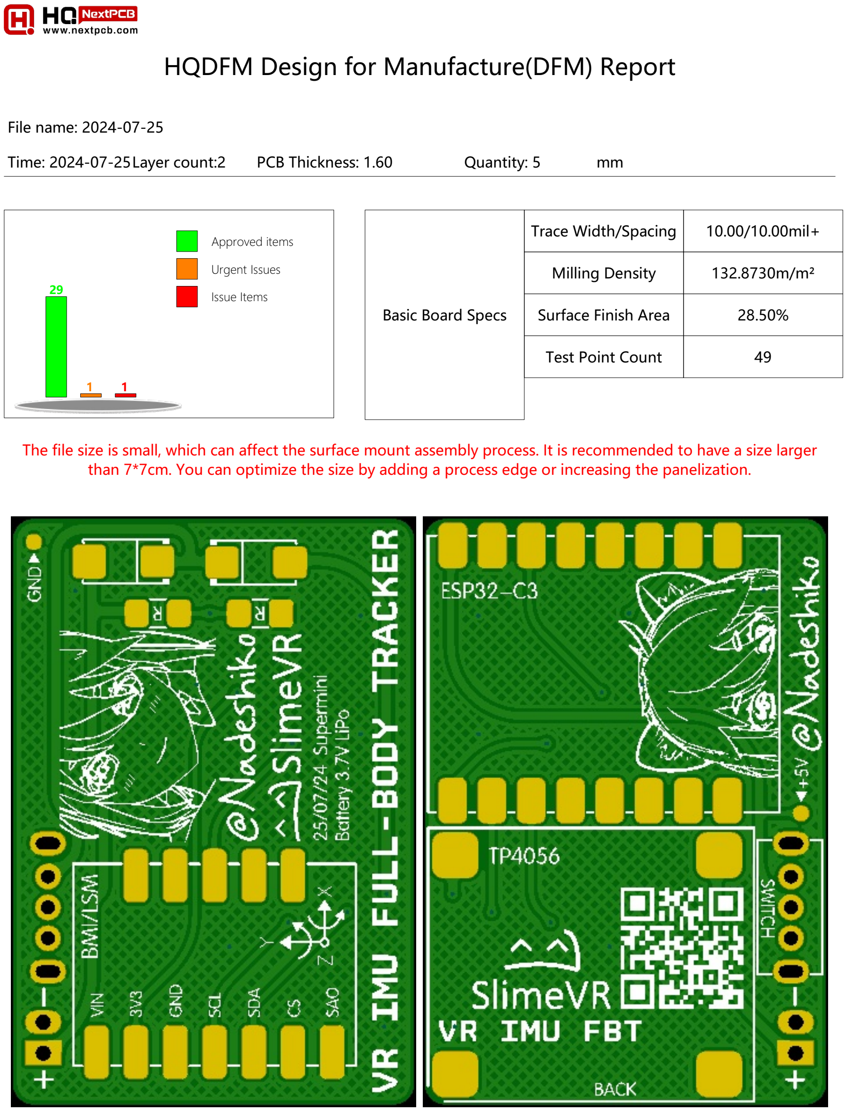
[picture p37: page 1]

File name: 2024-07-25

Time: 2024-07-25Layer count:2 | PCB Thickness: 1.60 | Quantity: 5
mm

Approved items

Urgent Issues

Issue Items

29

1 1

Basic Board Specs | Trace Width/Spacing | 10.00/10.00mil+
| Surface Finish Area | 28.50%
| Test Point Count | 49

The file size is small, which can affect the surface mount assembly process. It is recommended to have a size larger than 7*7cm. You can optimize the size by adding a process edge or increasing the panelization.

Type | Category | No. of Checks | Result
| Open/Shorts (IPC) | 1 | Fail
| Signal Integrity | 4 | Pass
| Smallest Trace Width | 1 | Pass 2
| Smallest Trace Spacing | 3 | Pass
| SMD Pad Spacing | 1 | Pass
| Pad Size | 3 | Pass 2
| Hatched Copper Pour | 2 | Pass 2
| Annular Ring Size | 2 | Pass 3
| Drill to Copper | 5 | Pass 37
| Copper-to-Board Edge | 2 | Pass 37
| Holes on SMD Pads | 4 | Pass
PCB Drilling Analysis | Drill Diameter | 8 | Pass 15 , Fail 1
| Drill Spacing | 4 | Pass
| Drill to Board Edge | 4 | Pass
| Drill Hole Density | 1 | Pass
| Special Drill Holes | 2 | Pass
| Drill Hole Errors | 3 | Pass
PCB Solder Mask Analysis | Solder Mask Dam | 2 | Pass
| Missing SMask Opening | 1 | Pass
| Solder Paste Area | 1 | Pass
PCB Silk Analysis | Silkscreen Spacing | 1 | Pass

PCB Trace Analysis

PCBA Component Analysis | Component Spacing | 1 | Fail
| Comp.-to-Board-Edge | 3 | Fail
| Componet Silkscreen Spacing | 0 | Fail
| Pad Count Mismatch | 2 | Fail
| Designator Length | 0 | Fail
| Double-sided Components | 1 | Pass
ComponentClearanceAnalysis | 1 | Pass
PCBA Pin Analysis | Pin-to-SMD Pad | 7 | Fail
| Through-hole Pins | 9 | Fail
| Pressfit Pins | 4 | Fail
PCBA Pad Analysis | Chip Pad | 60 | Fail
| Pad-Trace Connections | 4 | Pass 37
PCBA Fiducial Analysis | Fiducial Count | 1 | Fail
| Fiducial Analysis | 3 | Pass

ID | Check | Limits | Value | Issue | Image | Position | Qty | Level

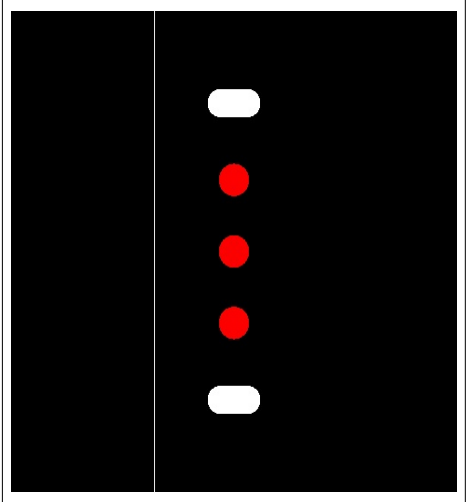
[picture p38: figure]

1

### Drill

Diameter_S
lot Aspect
Ratio

12,10,8

0.30

mm

Slots with aspect ratio of 2.00 were detected in your design. This could increase the risk of incomplete

### drilling of the slot, which

decrease manufacturing
efficiency and yield, and

### affect the reliability of the

boards. The ratio should be increased to at least 2:1

2.95,13.61 | 1 | Warnin g

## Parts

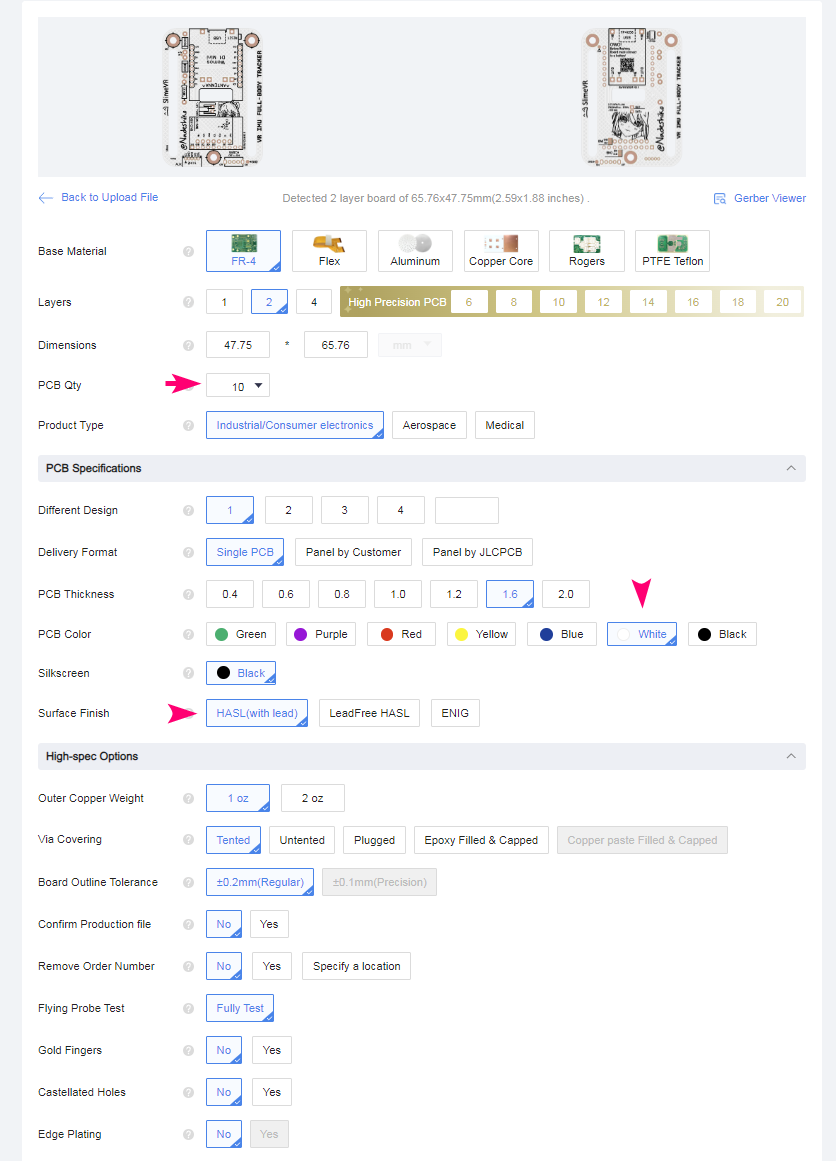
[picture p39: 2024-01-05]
Tracker Main/PCB Gerber/OrderingPCB.png

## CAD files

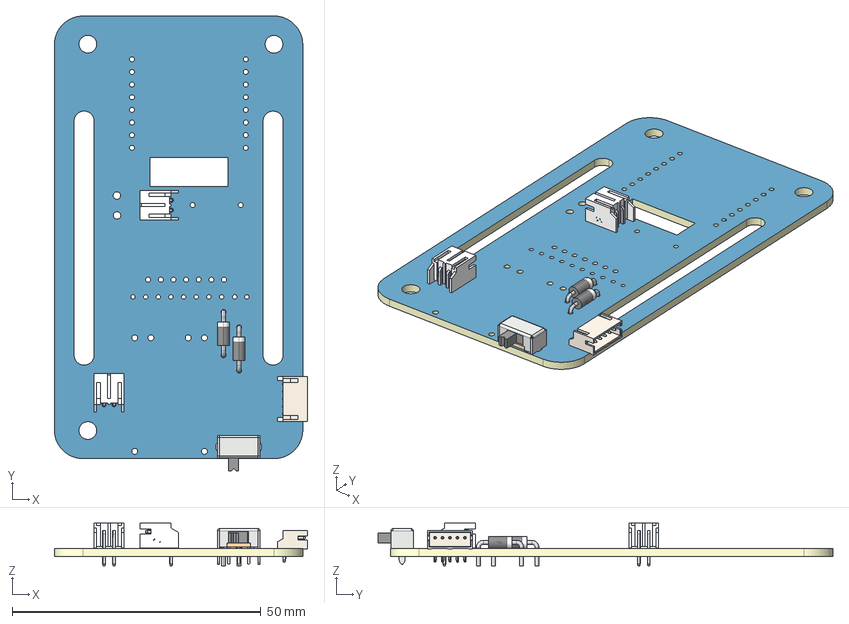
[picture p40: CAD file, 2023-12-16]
R2 Mini/CAD Step/3D_SlimeVR Nadeshiko R2 Mini-PCB_2023-12-16.step
50.9 x 91.4 x 8.55 mm
Board

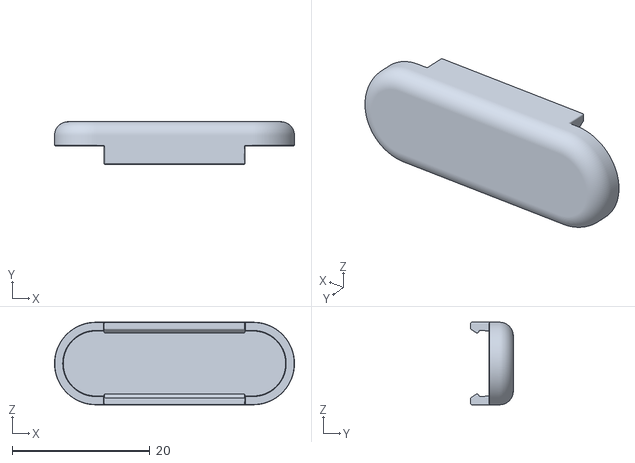
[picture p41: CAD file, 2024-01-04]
Tracker Extension/3D Print STL/SlimeVRNadeshikoExtension-ENDCAP.stl
34.9 x 6.20 x 12.0

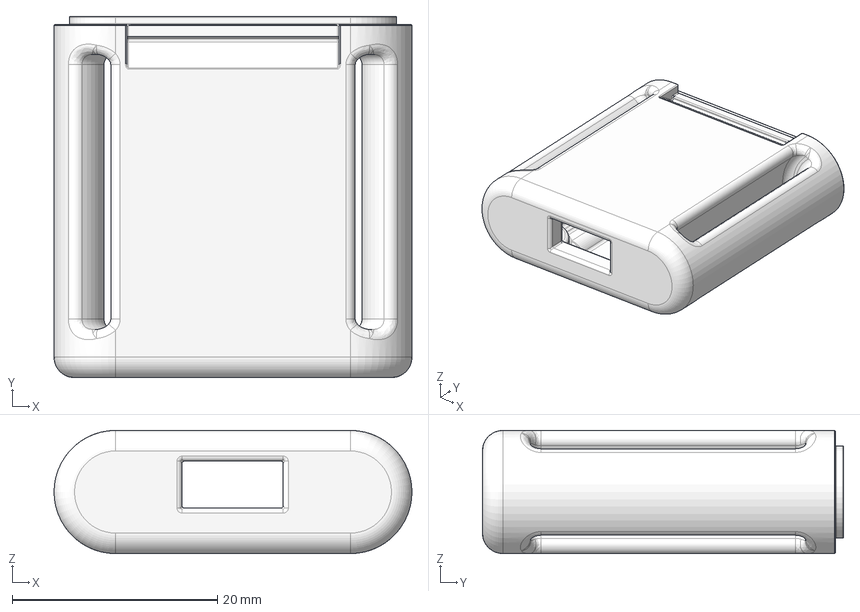
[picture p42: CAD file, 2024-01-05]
Tracker Extension/CAD Step/SlimeVR Nadeshiko Extension Part 1.step
34.9 x 35.2 x 12.0 mm

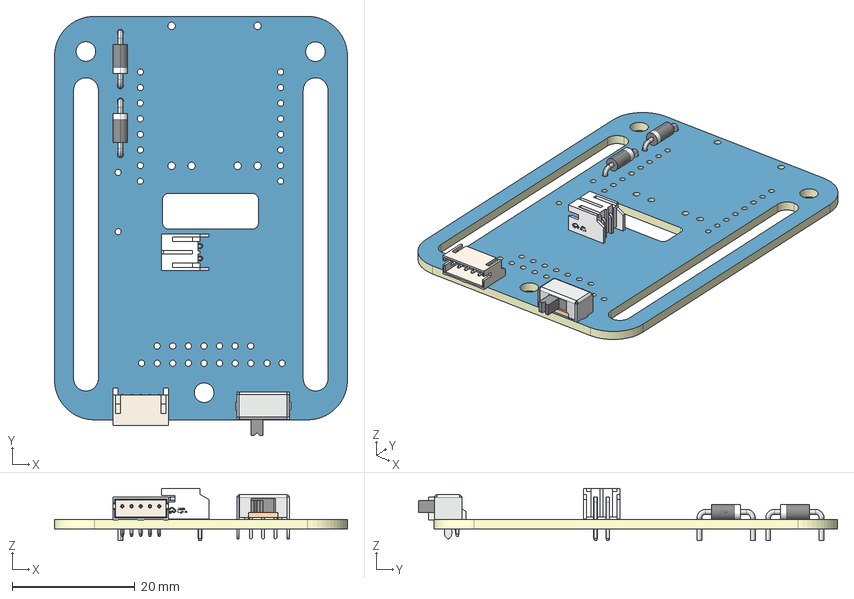
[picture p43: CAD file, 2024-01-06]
Tracker Main/CAD Step/PCB_3D_SlimeVR Nadeshiko R3_2024-01-06.step
47.7 x 68.3 x 8.55 mm
Board

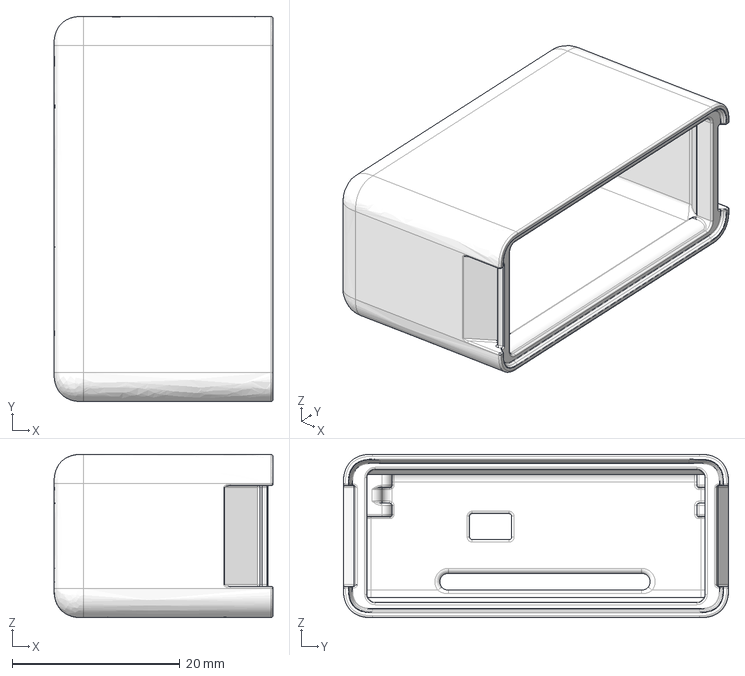
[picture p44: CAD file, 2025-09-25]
Tracker Supermini/CAD Step/NadeshikoSupermini - BASE.step
26.1 x 46.0 x 19.5 mm

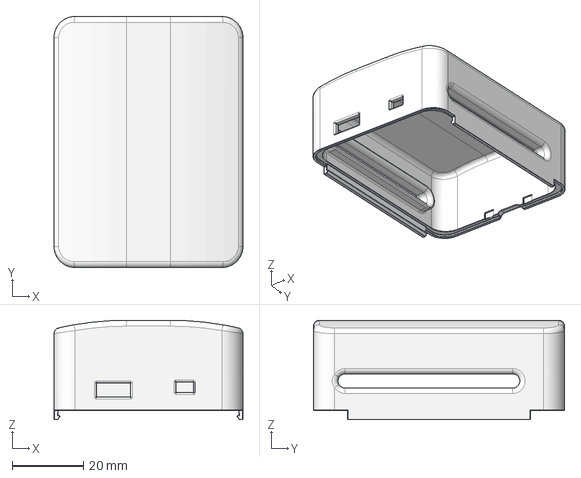
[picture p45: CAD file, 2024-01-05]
Tracker Main/CAD Step/SlimeVR Nadeshiko - Part 1.step
53.0 x 70.4 x 27.9 mm

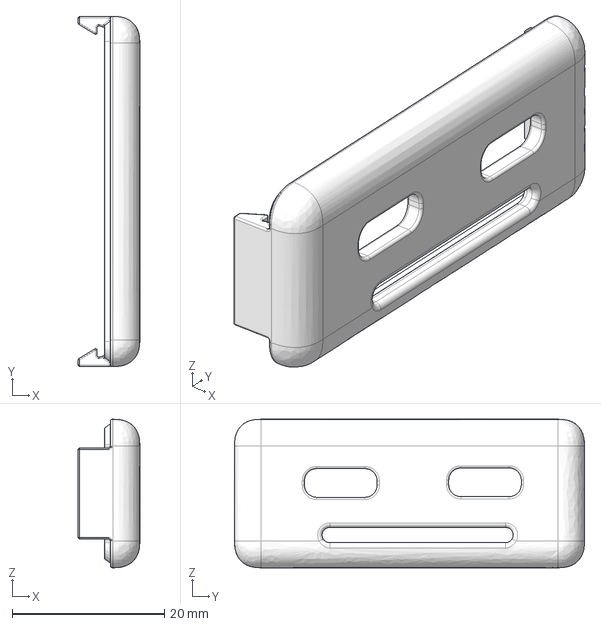
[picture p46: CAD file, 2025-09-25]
Tracker Supermini/CAD Step/NadeshikoSupermini - TOP.step
8.10 x 46.0 x 19.5 mm

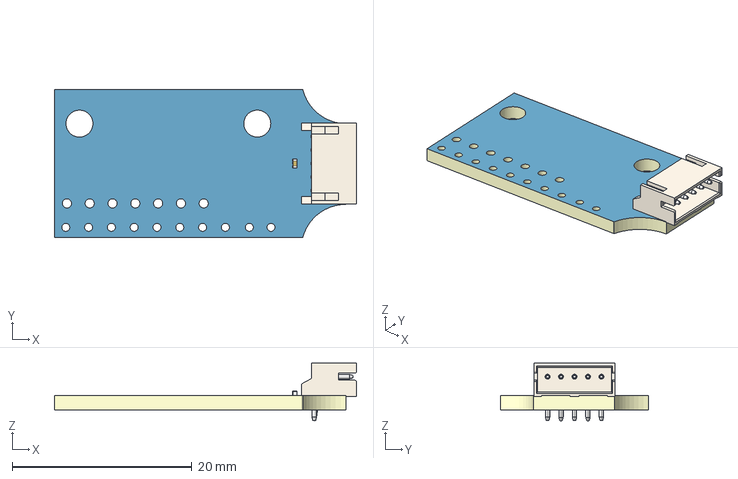
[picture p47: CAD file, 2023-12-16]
Tracker Extension/CAD Step/PCB_3D_SlimeVR Nadeshiko Extension_2023-12-12.step
33.6 x 16.5 x 6.42 mm
Board

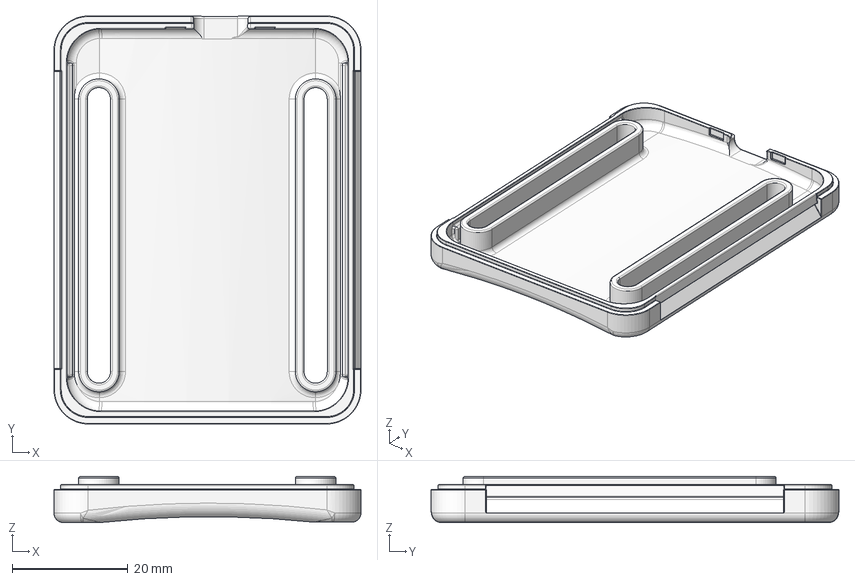
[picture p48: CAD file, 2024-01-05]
Tracker Main/CAD Step/SlimeVR Nadeshiko - Part 2.step
53.0 x 70.4 x 7.95 mm

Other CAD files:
Tracker Extension/CAD Step/SlimeVR Nadeshiko Extension Part 2.step

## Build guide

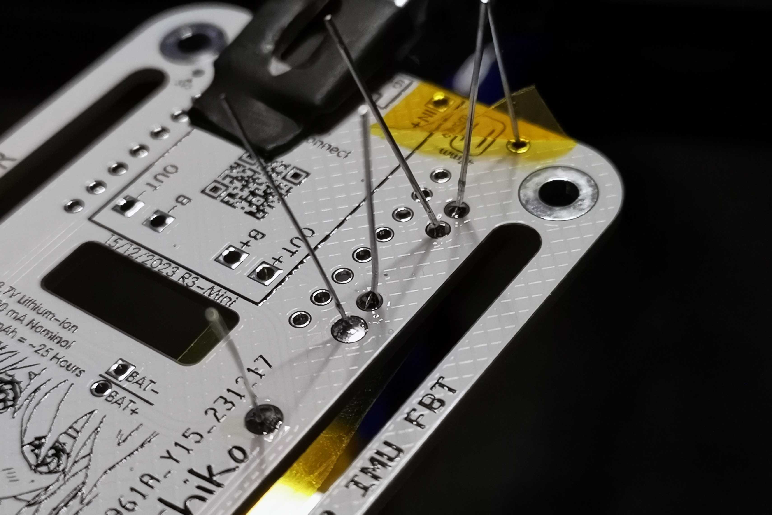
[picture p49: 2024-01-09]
Misc/Assembly/Step-2-ResDio-1/3.jpg

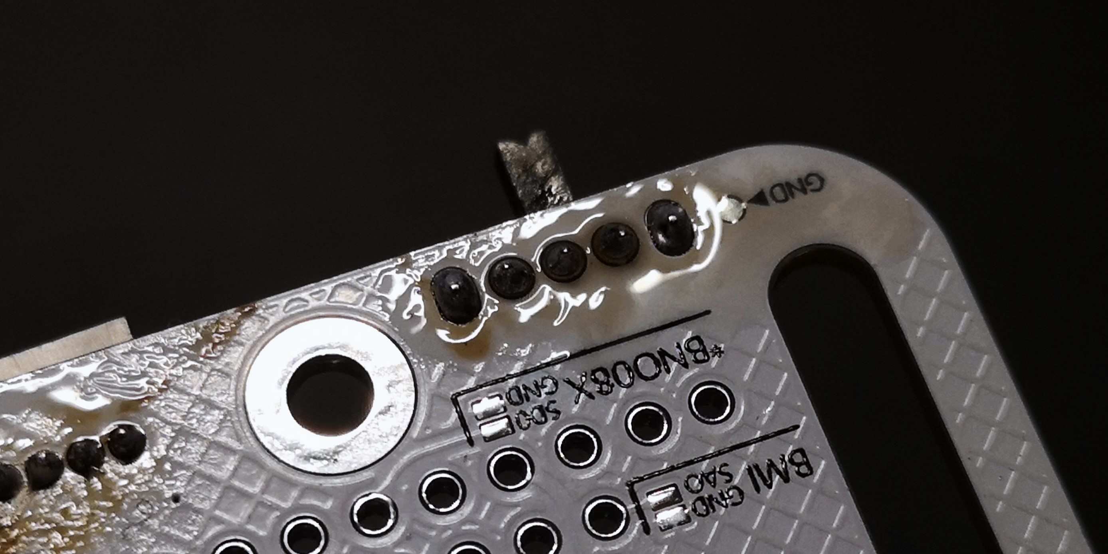
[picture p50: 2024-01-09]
Misc/Assembly/Step-6-5Pin-Switch/9.jpg

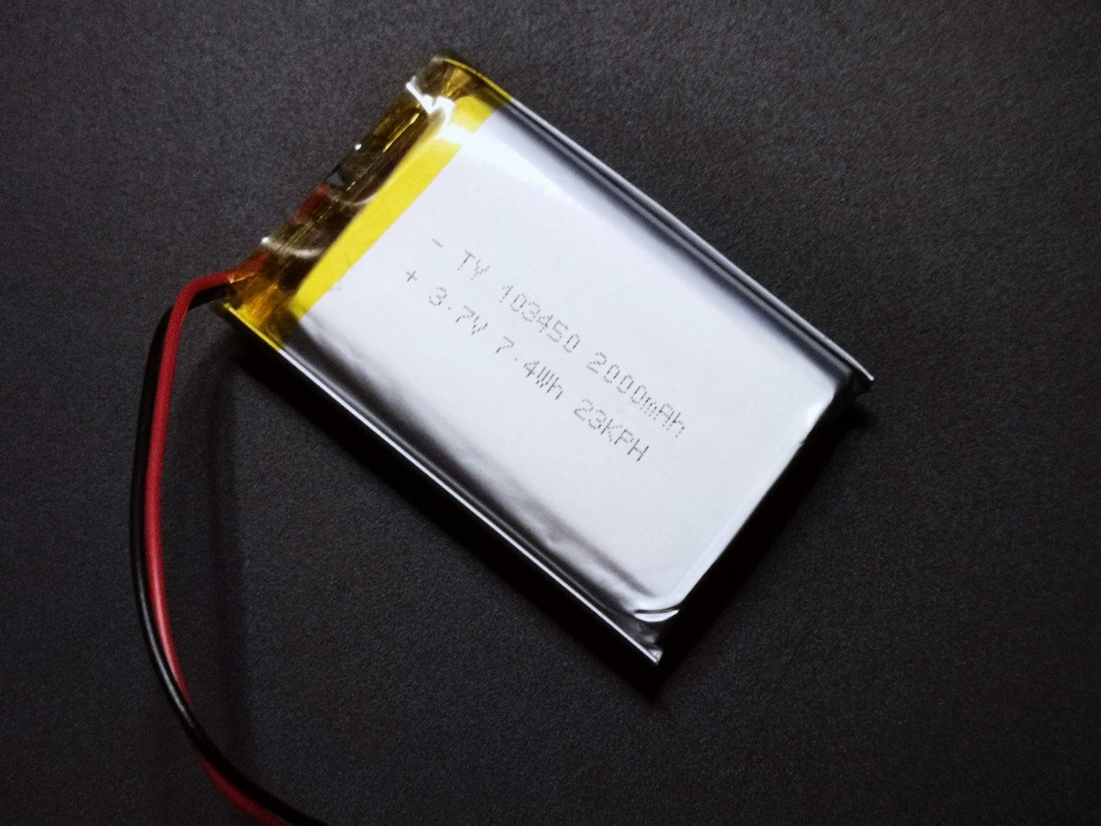
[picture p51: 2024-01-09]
Misc/Assembly/Step-10-Tape/2.jpg

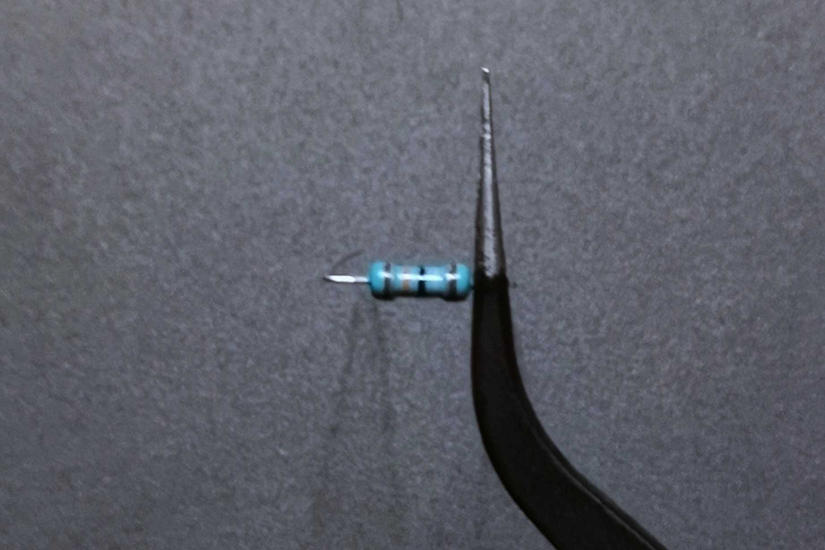
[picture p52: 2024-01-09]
Misc/Assembly/Step1-ResDio-Bend/3.jpg

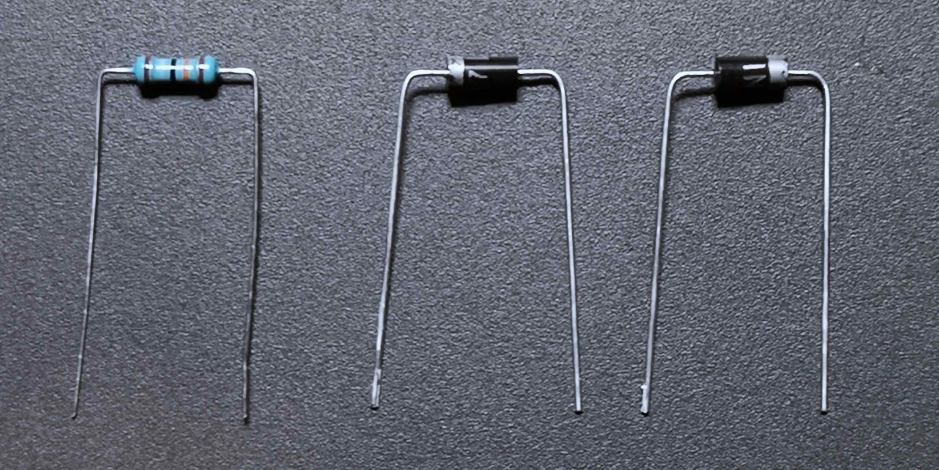
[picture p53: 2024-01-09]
Misc/Assembly/Step1-ResDio-Bend/4.jpg

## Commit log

2023-12-16 owo
    ayy
    [3D_SlimeVR Nadeshiko Extension_2023-12-12.step, 3D_SlimeVR Nadeshiko R2 Mini-PCB_2023-12-16.step, 3D_SlimeVR Nadeshiko-R3Mini-PCB_2023-12-15.step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]
2023-12-18 3DP Tolerances
    [3D_SlimeVR Nadeshiko R2 Mini-PCB_2023-12-16.step, SlimeVRNadeshikoExtension_ENDCAP.stl]
2023-12-24 Package Size
    0402 100nf capacitor changed to 0603 package as it's easier to solder by hand.
2024-01-01 Charging Dock
    [3D_Charging Dock PCB R3 Hand Solder_2023-12-31.step, BOM_Block_Charging Dock PCB R3 Hand Solder_2023-12-31.xlsx, USBPDDecoy.step]
2024-01-04 Release
    Fixes made from prototype prints and PCB.
    [3D_SlimeVR Nadeshiko Extension-ENDCAP.stl, SlimeVRNadeshikoExtension_ENDCAP.stl]
2024-01-04 Assembly Guide
2024-01-06 AUX header fix
    [PCB_3D_SlimeVR Nadeshiko R3_2024-01-05.step, PCB_3D_SlimeVR Nadeshiko R3_2024-01-06.step]
2024-01-06 -
    Updated previews images to latest PCB and case.
    [3D_Charging Dock PCB R3 Hand Solder_2023-12-31.step]
2024-01-06 Assembly Guide
    Simplified D1 Mini soldering.
    Cropped images a bit.
2024-01-08 Assembly Guide
    IMU Step improved
2024-01-09 -
    Removed charging dock stuff for now until new variant is complete.
    [BOM_Block_Charging Dock PCB R3 Hand Solder_2023-12-31.xlsx, USBPDDecoy.step]
2024-01-09 -
    Assembly guide image size reduction
2024-05-30 3D Case Files
    [NadeshikoMini - Part 1.step, NadeshikoMini - Part 2.step]
2024-05-30 -
    Hidden D1 assembly instructions
2024-05-30 -
    Caseless & Cased PCB info
2024-07-09 Case Update
    Internal PCB supports for a more solid hold on it when closed.
2024-07-09 Supermini Rev 4
    - PCB uses case space more efficiently - By moving both USB Type C of the ESP32-C3, TP4056 and the slide power switch on the same side of the PCB board as they are the tallest components.
    - Increased case battery space to support 602535 Li-Po cells.
    - Improved strap hole to be more closer to skin, which improves comfort and hold when mounted on wrist, ankle or feet.
    [NadeshikoMini - Part 1.step, NadeshikoMini - Part 2.step, NadeshikoSupermini - BASE.step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]
2024-07-09 -
    Removed Caseless version as it's not really needed considering how cheap the cases can be 3D printed for these e.e
2024-07-11 Gerber update
    Some silkscreen clean up, and board edge and via tolerances fixed so it comes out nicer looking.
2024-07-11 Case improvements
    - Internal PCB tolerance clean up and PCB hold/support improvements.
    - More refined cutie owo roundness to the outer edges.
    - Checked for JLCPCB SLA min/max guidelines and made changes to comply.
    [NadeshikoSupermini - BASE.step, NadeshikoSupermini - TOP.step]
2024-07-11 PCB Preview
2024-07-18 Update README.md
    Added some links for straps and trusted battery sellers.
2024-07-23 Case Updates
    Still waiting for PCB's to arrive to check everything fully and make assembly guide, but these are the changes done to the cases after testing them:
    - Moved snap fits to smaller edges for less flex and more secure fit.
    - Added extra wall thickness for less warp chance, flex and improves rigidity.
    - Added internal wall ribs to case and lid for less warp chance and flex when handling.
    - Less loose tolerances for USB-C connectors and improved shape to match connectors better.
    - Better shadow line interface and tolerance between the lid and case, less likely to rattle.
    - Strap hole moved higher so less flex is experienced on the bottom wall, reducing cracking to fatigue chance when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
2024-07-23 CAD
    CAD Step files updated to latest 3D print .stl's
    [NadeshikoSupermini - BASE.step, NadeshikoSupermini - TOP.step]
2024-07-25 Gerber Updates
    - Improved through hole pad size on battery connection and slide switch for easier hand soldering.
    - 1206 resistor pads can now also work with 0805 resistors and moved placement away from diodes and each other to be easier for hand soldering.
2024-08-15 Fixed Extension
    There was bridging between the 3v3 C1 0603 capacitor's pad to the ground fill due to incorrect ground fill generation. If you have ordered the previous extension and have extensions that do not boot, this can be solved by cutting the bridging with a knife.
2025-11-10 Double Batt Case Variant
    Added a new case variant that allows stacking two LiPo into parallel for extended usage time.
2026-03-17 Fix typos and add quarter-wave wire antenna section
    - Fix typos and grammar throughout README
    - Inconsistent decimal formatting in cost estimates
    - Obsolete BMI-270 IMU reference in flashing checklist
    - Various punctuation and sentence structure fixes
    Rename antenna section to "ESP32 C3 Supermini WiFi Antennas" and reorganize
    into two options:
    - Option A: IPEX antenna (Plus/V2 variant), with note explaining its
    limitations due to connector loss and missing ground plane
    - Option B: Quarter-wave wire antenna (any C3 variant), covering wire length
    calculation, soldering steps, U-shape bending for omnidirectional radiation
    pattern, PCB placement guidance, and tips for using battery cable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
